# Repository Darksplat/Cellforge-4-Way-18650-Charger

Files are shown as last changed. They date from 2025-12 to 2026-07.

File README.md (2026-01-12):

# CellForge – 4 Way 18650 Charger & Analytics Platform

CellForge is an open hardware and software project for testing, analysing, and cataloguing 18650 lithium-ion cells.

It is inspired by Brett Watt’s original ASCD Nano charger and extends the concept with modern hardware, Wi-Fi connectivity, and a web-based analytics platform.

This repository contains **firmware, hardware, documentation, and web platform components** required to build and operate a connected 4-bay charger.

---

## Project Components

### Hardware
- 4-slot 18650 charger / discharger
- TP5100 charge controllers per slot
- Dual ADS1115 (16-bit I²C ADCs)
  - Battery voltage sensing
  - Load / discharge voltage sensing
- DS18B20 temperature sensors
- Active cooling with PWM fan control
- 3.3 V logic throughout (ESP32-safe)

### Firmware
- Target: **Arduino Nano ESP32 (ESP32-S3)**
- Wi-Fi connectivity
- Server heartbeat (PING) protocol
- RSSI (signal strength) reporting
- Internal resistance measurement
- Capacity and energy calculation
- Modular PlatformIO-based build

### Web Platform
- PHP + MySQL backend
- User authentication
- Charger registration and claiming
- Live charger connectivity status
- Signal strength visualisation
- Cell inventory
- Run ingestion (start, IR, complete, error)
- Cron-based offline detection

### Data
- Cell metadata (barcode-centric)
- Internal resistance results
- Capacity (mAh) and energy (Wh)
- Charger telemetry (presence, RSSI)

---

## Current Status

- Firmware: **Stable, Wi-Fi enabled**
- Connectivity: **Server-authoritative heartbeat**
- Telemetry: **RSSI reporting live**
- Offline detection: **Cron-enforced**
- UI: **Live status, signal bars, local time rendering**

---

## Repository Structure (high-level)

---

## Design Principles

- Server decides truth (presence, offline state)
- Firmware reports facts, not assumptions
- Browser renders user-local time
- Hardware remains Brett-compatible where practical
- Electrical safety first (3.3 V logic, no mixed-voltage traps)

---

## Licensing

Original ASCD Nano work:
- © Brett Watt
- Creative Commons BY-NC-SA 3.0

CellForge modifications:
- © Jeremy Younger
- Released under the same license unless otherwise stated

---

## Disclaimer

This project involves lithium-ion cells.
Improper use can result in fire, injury, or property damage.

You are responsible for ensuring safe construction, operation, and supervision.

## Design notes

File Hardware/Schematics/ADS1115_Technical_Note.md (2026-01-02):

ADS1115 Technical Note
Rationale, Configuration, and Integration in V2
This note explains why the ADS1115 was selected, how it is configured in the V2 schematic, and how it replaces the analogue multiplexer used in Brett’s original Arduino Nano design.
1. Why ADS1115 was chosen
The ADS1115 was selected to address the key limitations of the original analogue sensing approach:
Limitations in V1 (mux + MCU ADC)
10-bit ADC resolution (ATmega328P)
Shared SIG line susceptible to:
switching transients
settling-time errors
Sequential sampling via S0–S3
Firmware complexity around mux timing
Advantages of ADS1115
16-bit resolution (up to 32768 counts)
True differential-capable architecture (used single-ended here)
Per-channel input sampling without analogue switching
Stable, repeatable readings
Operates natively at 3.3 V
Widely supported, proven, inexpensive
The ADS1115 provides cleaner data with simpler firmware, without changing the charger’s electrical behaviour.
2. ADS1115 role in the V2 design
Two ADS1115 devices are used:
Device	I²C Address	Purpose
ADS1115 #1	0x48 (ADDR = GND)	Battery voltages BV1–BV4
ADS1115 #2	0x49 (ADDR = 3V3)	Load voltages RV1–RV4
Each ADS1115 uses:
Single-ended inputs
One channel per measurement
Shared I²C bus (SDA/SCL)
This mirrors the logical separation Brett already used (battery vs load sensing), just without the mux.
3. Electrical configuration (schematic-level)
Power
VDD = 3.3 V
GND = system ground
Local 100 nF decoupling capacitor per ADS1115
I²C
SDA / SCL pulled up to 3.3 V
No level shifting required
ALERT/RDY pin unused (left unconnected)
Address selection
ADDR tied to GND → address 0x48
ADDR tied to 3V3 → address 0x49
This avoids bus contention and allows both devices to coexist cleanly.
4. Firmware implications (high level)
What is removed
No S0–S3 control
No SIG analogue reads
No mux settling delays
What replaces it
Each voltage is read directly:
ads.readADC_SingleEnded(channel);
Where channel is 0–3 corresponding to BVx or RVx.
Scaling
The existing resistor divider ratios remain unchanged
Only the ADC conversion changes
Brett’s original scaling math is reused
This keeps calibration and interpretation consistent with the original design.
5. Performance and reliability benefits
Practical improvements
Less noise on voltage readings
No cross-channel coupling
Better low-current / near-end-of-charge resolution
More consistent logging results
System-level benefits
Simplified schematic
Fewer failure points
Easier debugging
Cleaner PCB routing
6. What ADS1115 does not change
To be explicit, ADS1115 does not:
Alter TP5100 charge behaviour
Change DFET/CFET control logic
Affect timing of charge/discharge cycles
Replace any safety or control logic
It is a measurement upgrade only.
7. Summary
The ADS1115 replaces the analogue multiplexer and MCU ADC with a dedicated, high-resolution measurement subsystem that:
Preserves Brett’s original design intent
Improves accuracy and reliability
Simplifies both schematic and firmware
Aligns naturally with a 3.3 V ESP32 platform
It is a modernisation, not a redesign.

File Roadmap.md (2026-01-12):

# CellForge Roadmap

This roadmap describes the intended development direction of the CellForge project.
It is not a promise of timelines; items may move or change as the project evolves.

The focus is on reliability, safety, and real-world usability.

---

## Firmware

### Completed
- ESP32 Nano (ESP32-S3) platform migration
- Wi-Fi connectivity
- Server heartbeat (PING) protocol
- Connection state reporting (CONNECTED / CONNECTING)
- RSSI (Wi-Fi signal strength) reporting
- ADS1115 external ADC integration
- PWM fan control using ESP32 `ledc`
- Multi-sensor temperature support
- Legacy compatibility for original state machine logic

### Planned
- Firmware build/version reporting to server
- Charger-side error codes surfaced in UI
- Optional heartbeat interval configuration
- OTA update strategy (future, not immediate)

---

## Hardware

### Completed
- ESP32-safe 3.3 V logic domain
- Dual ADS1115 voltage measurement architecture
- Removal of analogue multiplexer
- TP5100 charge status GPIO integration
- Shift-register-based MOSFET control
- Electrical rule check (ERC) validation

### Planned
- PCB V2 layout validation
- Thermal optimisation review
- Enclosure finalisation
- Connector and strain relief improvements

---

## Website / Backend

### Completed
- User authentication (register / login / logout)
- Charger registration via API token
- Charger claiming workflow
- Live connection status indicators
- RSSI signal strength visualisation
- Local-time rendering for timestamps
- Cron-based offline detection
- Runs ingest pipeline (start, IR, complete, error)
- Cell inventory management

### Planned
- Per-charger detail pages
- Charger telemetry history (RSSI, uptime)
- Run history visualisation (charts)
- Per-cell performance trends
- Alerts (offline, weak signal, failed runs)
- Data export (CSV / JSON)

---

## Documentation

### Completed
- Changelog
- Project README
- Roadmap

### Planned
- Firmware flashing and recovery guide
- Hardware build and wiring guide
- API reference documentation
- Safety and operating guidelines

---

## Data & Integrations

### Completed
- Core schema for users, chargers, cells, and runs

### Planned
- Second Life Storage data scraping (cell metadata, images)
- Cell model normalisation
- Historical trend analysis

---

## Guiding Principles

- Server determines truth for connectivity and state
- Firmware reports measurements and facts only
- UI reflects backend state, not inference
- Safety and electrical correctness over speed
- Backward compatibility with Brett Watt’s design where practical

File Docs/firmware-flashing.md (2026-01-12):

# Firmware Flashing and Recovery Guide
## Arduino Nano ESP32 (ESP32-S3)

This document describes how to build, flash, and recover CellForge firmware on the Arduino Nano ESP32 (ESP32-S3).
It also documents common errors and their resolutions.

---

## Supported Hardware

- Arduino Nano ESP32 (ESP32-S3)
- USB-C connection (data-capable cable required)

---

## Build Environment

Recommended:
- PlatformIO (VS Code)

Supported:
- Arduino IDE (limited debugging support)

---

## Firmware Location

Firmware
- ASCD_Nano_PIO
  - ASCD_Nano_Cellforge
    - src
      - ASCD_Nano.ino
      - Pins.h
      - Secrets.h
      - WifiManager.h
      - StatusLED.h

---

## Configuration (Secrets.h)

Before flashing, ensure `Secrets.h` is configured.

Example:

```cpp
#pragma once

#define WIFI_SSID "your_wifi_ssid"
#define WIFI_PASSWORD "your_wifi_password"
#define CELLFORGE_API_TOKEN "your_api_token_here"

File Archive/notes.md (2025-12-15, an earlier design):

## Archived material
The contents of the `archive/` directory are provided for historical and
reference purposes only. Licensing and attribution remain with the original
authors and sources. This material is not relicensed under the MIT License
unless explicitly stated.

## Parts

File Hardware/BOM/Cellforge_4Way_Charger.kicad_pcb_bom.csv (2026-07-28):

Designator | Quantity | Value | Footprint | Package | MPN | DNP | Mount_Type | Description | MF | MAXIMUM_PACKAGE_HEIGHT | Price | Check_prices | STANDARD | PARTREV | SnapEDA_Link | MP | Description_1 | Availability | MANUFACTURER | Sim.Device | Sim.Pins
A1 | 1 | Arduino_Nano_ESP32 | Arduino_Nano |  |  |  | tht | Arduino Nano board based on the ESP32-S3 with a dual-core 240 MHz processor, 384 kB ROM, 512 kB SRAM. Operates at 3.3V, with 5V USB-C® input and 6-21V VIN. Features Wi-Fi®, Bluetooth® LE, digital and analog pins, and supports SPI, I2C, UART, I2S, and CAN.
BT1 | 1 | BK-18650-PC8 | BAT_BK-18650-PC8 | None |  |  | tht |  | MPD | 21.54 mm | None | https://www.snapeda.com/parts/BK-18650-PC8/MPD/view-part/?ref=eda | Manufacturer Recommendations | L | https://www.snapeda.com/parts/BK-18650-PC8/MPD/view-part/?ref=snap | BK-18650-PC8 | Battery Holder (Open) 18650 4 Cell PC Pin | In Stock | MPD
BZ1 | 1 | Buzzer | Buzzer_15x7.5RM7.6 |  |  |  | tht | Buzzer, polarized
C1, C11, C2 | 3 | 100uF | CP_Radial_D5.0mm_P2.00mm |  |  |  | tht | Polarized capacitor
C10, C13, C3, C4, C5, C6, C7, C8, C9 | 9 | 100nF | C_0603_1608Metric_Pad1.08x0.95mm_HandSolder |  |  |  | smt | Unpolarized capacitor
C12, C16, C17, C18 | 4 | C | C_Disc_D5.0mm_W2.5mm_P2.50mm |  |  |  | tht | Unpolarized capacitor
C14 | 1 | 10nF | C_0603_1608Metric_Pad1.08x0.95mm_HandSolder |  |  |  | smt | Unpolarized capacitor
D1 | 1 | 1N4007 | D_DO-41_SOD81_P10.16mm_Horizontal |  |  |  | tht | 1000V 1A General Purpose Rectifier Diode, DO-41 |  |  |  |  |  |  |  |  |  |  |  | D | 1=K 2=A
J1 | 1 | Jack-DC | BarrelJack_CUI_PJ-063AH_Horizontal_CircularHoles |  |  |  | tht | DC Barrel Jack
J2 | 1 | Conn_01x02_MountingPin | JST_XH_B2B-XH-A_1x02_P2.50mm_Vertical |  |  |  | tht | Generic connectable mounting pin connector, single row, 01x02, script generated (kicad-library-utils/schlib/autogen/connector/)
J3, J4, J6, J7 | 4 | Screw_Terminal_01x02 | TerminalBlock_Phoenix_PT-1,5-2-5.0-H_1x02_P5.00mm_Horizontal |  |  |  | tht | Generic screw terminal, single row, 01x02, script generated (kicad-library-utils/schlib/autogen/connector/)
J5 | 1 | Conn_01x04_Socket | PinSocket_1x04_P2.54mm_Vertical |  |  |  | tht | Generic connector, single row, 01x04, script generated
J8 | 1 | Conn_01x02_Pin | PADS |  |  |  | smt | Generic connector, single row, 01x02, script generated
Q1 | 1 | BD139 | TO-126-3_Vertical |  |  |  | tht | 1.5A Ic, 80V Vce, Low Voltage Transistor, TO-126
Q10, Q6, Q7, Q9 | 4 | BC547 | TO-92_Inline |  |  |  | tht | 0.1A Ic, 45V Vce, Small Signal NPN Transistor, TO-92
Q11, Q12, Q13, Q14, Q15, Q16, Q17, Q19 | 8 | IRLZ44N | TO-220-3_Vertical |  |  |  | tht | 47A Id, 55V Vds, 22mOhm Rds Single N-Channel HEXFET Power MOSFET, TO-220AB
Q18, Q20, Q21, Q22 | 4 | FQP27P06 | TO-220-3_Vertical |  |  |  | tht | -27A Id, -60V Vds, QFET P-Channel MOSFET, TO-220
Q2, Q23, Q3, Q8 | 4 | AO3401A | SOT-23 |  |  |  | smt | -4.0A Id, -30V Vds, P-Channel MOSFET, SOT-23
R1, R21, R32, R36 | 4 | 4.7K | R_1206_3216Metric_Pad1.30x1.75mm_HandSolder |  |  |  | smt | Resistor
R10, R11, R12, R13, R14, R15, R16, R17, R18, R19, R4, R5, R6, R7, R8, R9 | 16 | 100K | R_1206_3216Metric_Pad1.30x1.75mm_HandSolder |  |  |  | smt | Resistor
R2, R20, R3, R35, R43, R50 | 6 | 10K | R_1206_3216Metric_Pad1.30x1.75mm_HandSolder |  |  |  | smt | Resistor
R22 | 1 | 1K | R_1206_3216Metric_Pad1.30x1.75mm_HandSolder |  |  |  | smt | Resistor
R23 | 1 | 1k | R_1206_3216Metric_Pad1.30x1.75mm_HandSolder |  |  |  | smt | Resistor
R33, R34, R37, R38, R39, R40, R41, R42, R44 | 9 | 470R | R_1206_3216Metric_Pad1.30x1.75mm_HandSolder |  |  |  | smt | Resistor
SW1 | 1 | SW_Push | SW_PUSH_6mm |  |  |  | tht | Push button switch, generic, two pins
TP5100_Module1, TP5100_Module2, TP5100_Module3, TP5100_Module4 | 4 | ~ | Untitled |  |  |  | tht
U1, U2, U3, U4, U7 | 5 | DS18B20 | TO-92_Inline |  |  |  | tht | Programmable Resolution 1-Wire Digital Thermometer TO-92
U5 | 1 | 74HC595 | DIP-16_W7.62mm |  |  |  | tht | 8-bit serial in/out Shift Register 3-State Outputs
U6, U9 | 2 | ZC261500 | MODULE_ZC261500 | None |  |  | tht |  | YKS | NA | None | https://www.snapeda.com/parts/ZC261500/YKS/view-part/?ref=eda | Manufacturer Recommendations | NA | https://www.snapeda.com/parts/ZC261500/YKS/view-part/?ref=snap | ZC261500 | ADS1115 Module ADC 4 channel with Pro Gain Amplifier for Arduino RPi | Not in stock | YKS

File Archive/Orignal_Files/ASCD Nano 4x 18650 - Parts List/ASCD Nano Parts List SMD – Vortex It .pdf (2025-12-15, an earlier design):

### The Wayback Machine - https://web.archive.org/web/20220126044014/https://www.vortexi…

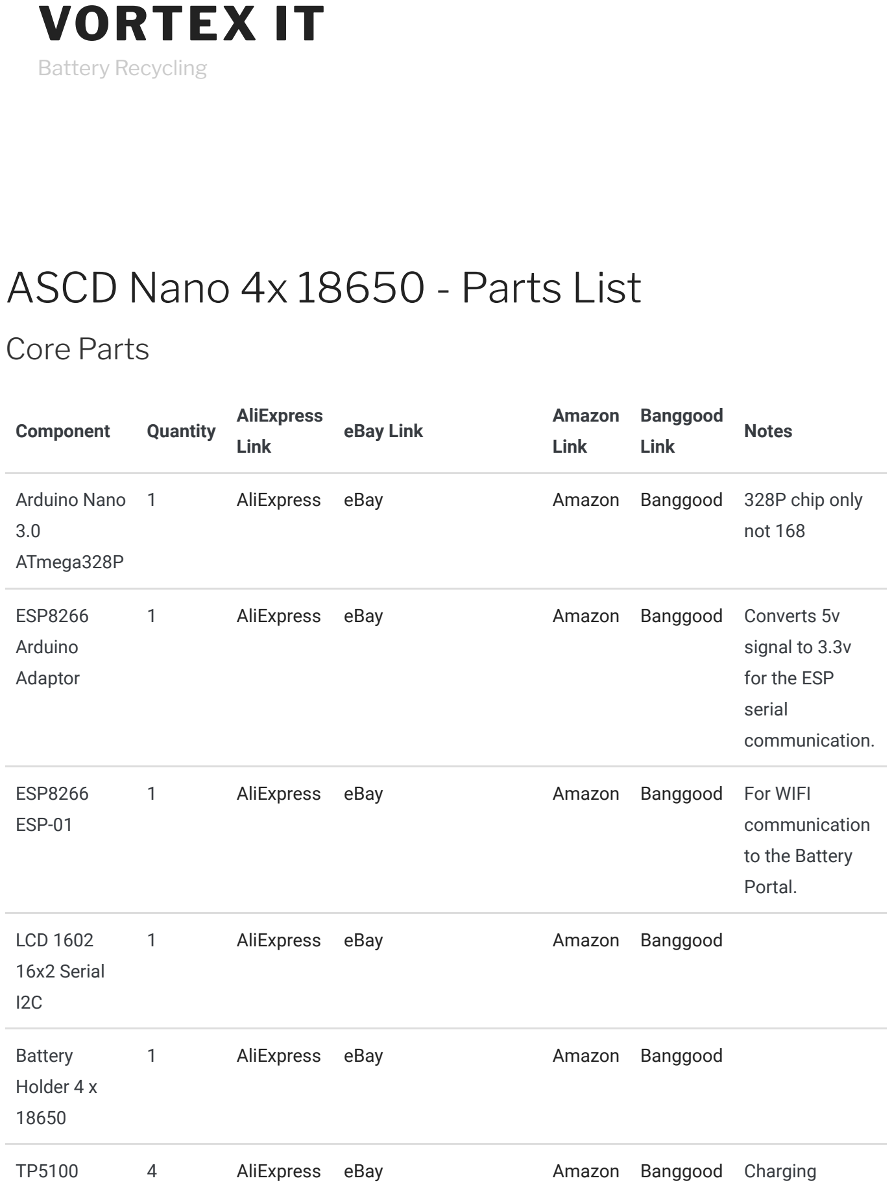
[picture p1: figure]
ASCD Nano 4x 18650 - Parts List; Core Parts; Component; Quantity; AliExpress; Link; eBay Link; Amazon Link; Banggood Link; Notes; Arduino Nano 3.0 ATmega328P; AliExpress eBay; Amazon Banggood 328P chip only; not 168; ESP8266 Arduino Adaptor; Amazon Banggood Converts 5v; signal to 3.3v for the ESP serial communication.; ESP8266 ESP-01; Amazon Banggood For WIFI; communication to the Battery Portal.; LCD 1602 16x2 Serial I2C; Amazon Banggood; Battery Holder 4 x 18650; Amazon Banggood Charging; VORTEX IT; Battery Recycling

Module | | modules. Check PCB footprint.

CD74HC4067
Module
1 | AliExpress (https://web.archive.org/web/20220126044014/http://bit.ly/2G0dxFU) eBay (https://web.archive.org/web/20220126044014/https://ebay.us/WXJNwM) | Amazon (https://web.archive.org/web/20220126044014/https://amzn.to/2ZuhIP1) Banggood (https://web.archive.org/web/20220126044014/https://www.banggood.com/custlink/DK33amgB9K) Be careful on PCB size some are larger

74HC595N
DIP16
1 | AliExpress (https://web.archive.org/web/20220126044014/http://bit.ly/2RIV9Tc) eBay (https://web.archive.org/web/20220126044014/https://ebay.us/LD0g7W) | Amazon (https://web.archive.org/web/20220126044014/https://amzn.to/2Hq9hhk) Banggood (https://web.archive.org/web/20220126044014/https://www.banggood.com/custlink/KGKKOm4b8d) Shift out Register
DIP16 Socket 1 | AliExpress (https://web.archive.org/web/20220126044014/http://bit.ly/2FePNOb) eBay (https://web.archive.org/web/20220126044014/https://ebay.us/mmJGwL) | Amazon (https://web.archive.org/web/20220126044014/https://amzn.to/2KYAE4k) Banggood (https://web.archive.org/web/20220126044014/https://www.banggood.com/custlink/Km3vlG4QZ6)

Temp Sensor
DS18B20
5 | AliExpress (https://web.archive.org/web/20220126044014/http://bit.ly/2T17VOt) eBay (https://web.archive.org/web/20220126044014/https://ebay.us/SWY1sO) | Amazon (https://web.archive.org/web/20220126044014/https://amzn.to/2NvYIgu) Banggood (https://web.archive.org/web/20220126044014/https://www.banggood.com/custlink/G3vGo3eAIU) Tes before soldering.

Tactile
Switch 6MM
1 | AliExpress (https://web.archive.org/web/20220126044014/http://bit.ly/2qFAR1j) eBay (https://web.archive.org/web/20220126044014/https://ebay.us/pZmwQm) | Amazon (https://web.archive.org/web/20220126044014/https://amzn.to/2KW5OcE) Banggood (https://web.archive.org/web/20220126044014/https://www.banggood.com/custlink/vD3ma3gslv)

Connector
KF301-2P
5.08mm
4 | AliExpress (https://web.archive.org/web/20220126044014/http://bit.ly/2PQP1uB) eBay (https://web.archive.org/web/20220126044014/https://ebay.us/JwZTQG) | Amazon (https://web.archive.org/web/20220126044014/https://amzn.to/2ZgH6fP) Banggood (https://web.archive.org/web/20220126044014/https://www.banggood.com/custlink/3DDvjGeNaE) Optional - For connecting the Discharge resistors or JST

DC Jack 5.5 x
2.1mm
1 | AliExpress (https://web.archive.org/web/20220126044014/http://bit.ly/2DsUyC7) eBay (https://web.archive.org/web/20220126044014/https://ebay.us/suEAMA) | Amazon (https://web.archive.org/web/20220126044014/https://amzn.to/2Nzxiqj) Banggood (https://web.archive.org/web/20220126044014/https://www.banggood.com/custlink/GmK3j34An5) 12V power input

Resistor
Carbon Film
3.3ohm 5W
4 | AliExpress (https://web.archive.org/web/20220126044014/http://bit.ly/2Niuaer) eBay (https://web.archive.org/web/20220126044014/https://ebay.us/b2B56O) | Amazon (https://web.archive.org/web/20220126044014/https://amzn.to/2ZrIs6K) Banggood (https://web.archive.org/web/20220126044014/https://www.banggood.com/custlink/mmGKl30kyn) Banggood is 3Ohm Aluminum. 6.8Ohm for 500mA discharge.

Conical
Rubber Feet
14x8mm
8 | AliExpress (https://web.archive.org/web/20220126044014/http://bit.ly/2zGEQ1G) eBay (https://web.archive.org/web/20220126044014/https://ebay.to/2SYO5TG) | Amazon (https://web.archive.org/web/20220126044014/https://amzn.to/323tYHR) Banggood (https://web.archive.org/web/20220126044014/https://www.banggood.com/custlink/vv3GlDgzrW) For non 3D print case design screwed to 35mm standoffs

Insulating
Washers
3x7x0.8mm
16 | AliExpress (https://web.archive.org/web/20220126044014/http://bit.ly/2Dy5A8X) eBay (https://web.archive.org/web/20220126044014/https://ebay.us/9Nb9U8) | Amazon (https://web.archive.org/web/20220126044014/https://amzn.to/2Zqf8JB) Banggood (https://web.archive.org/web/20220126044014/https://www.banggood.com/custlink/mKKvLKe2Ca) Bangood link is nylon

M3 x 12mm
Flat Head
Stainless
Steel 304
Hex Socket
Screw
8 | AliExpress (https://web.archive.org/web/20220126044014/http://bit.ly/2uMlM0i) https://ebay.us/Z9pBrK Amazon (https://web.archive.org/web/20220126044014/https://amzn.to/327cpGU) Banggood (https://web.archive.org/web/20220126044014/https://www.banggood.com/custlink/3GGmj34qCQ) Optional - Used to mount the board and Battery Holder

M3 304
Stainless
Steel 304
Hex Nuts
4 | AliExpress (https://web.archive.org/web/20220126044014/http://bit.ly/2OdxLMr) eBay (https://web.archive.org/web/20220126044014/https://ebay.us/gZtNj0) | Amazon (https://web.archive.org/web/20220126044014/https://amzn.to/322Kzvm) Banggood (https://web.archive.org/web/20220126044014/https://www.banggood.com/custlink/KDmvLGBqPt) Optional - Used to mount the Battery Holder

M3 Standoff
18mm Brass
F-F
4 | AliExpress (https://web.archive.org/web/20220126044014/http://bit.ly/2PUnAA4) eBay (https://web.archive.org/web/20220126044014/https://ebay.to/2PUyDcO) | Amazon (https://web.archive.org/web/20220126044014/https://amzn.to/2HoBmWk) Banggood (https://web.archive.org/web/20220126044014/https://www.banggood.com/custlink/DvDmomeMFQ) For LCD mounting. Banggood link is for a pack

M3 Standoff
35mm brass
F-F
4 | AliExpress (https://web.archive.org/web/20220126044014/http://bit.ly/2PUnAA4) eBay (https://web.archive.org/web/20220126044014/https://ebay.to/2PUyDcO) | Amazon (https://web.archive.org/web/20220126044014/https://amzn.to/2L3GEra) Banggood (https://web.archive.org/web/20220126044014/https://www.banggood.com/custlink/DvDmomeMFQ) Optional - For non 3D print case standoffs. Banggood link is for a pack

Header
Female
2.54mm 1x4
1 | AliExpress (https://web.archive.org/web/20220126044014/http://bit.ly/2ZyXOCA) eBay (https://web.archive.org/web/20220126044014/https://ebay.to/2Hv9Tm2) | Amazon (https://web.archive.org/web/20220126044014/https://amzn.to/2ZtUOqP) Banggood (https://web.archive.org/web/20220126044014/https://www.banggood.com/custlink/3KmmoDBU8z) Bangood link is 40pin cut to size

Headers
Male
2.54mm
1x40 Pin
1 | AliExpress (https://web.archive.org/web/20220126044014/http://bit.ly/2KZBU7q) eBay (https://web.archive.org/web/20220126044014/https://ebay.to/2RRsITf) | Amazon (https://web.archive.org/web/20220126044014/https://amzn.to/2Hsvn2H) Banggood (https://web.archive.org/web/20220126044014/https://www.banggood.com/custlink/KvmDOv0zZo) Used for all headers

Header
Female Right
Angle
2.54mm 1x4
1 | AliExpress (https://web.archive.org/web/20220126044014/http://bit.ly/2qEVQ4f) eBay (https://web.archive.org/web/20220126044014/https://ebay.to/2qJ0kH3) | Amazon (https://web.archive.org/web/20220126044014/https://amzn.to/2KYF7nC) Banggood (https://web.archive.org/web/20220126044014/https://www.banggood.com/custlink/3KmmoKB2jv) For the ESP Adaptor. Banggood is a stackable 8P. Need to cut to size and bend.

USB to
ESP8266
ESP-01
1 | AliExpress (https://web.archive.org/web/20220126044014/http://bit.ly/2DABm5i) eBay (https://web.archive.org/web/20220126044014/https://ebay.to/2FkfrAY) | Amazon (https://web.archive.org/web/20220126044014/https://amzn.to/2ZrMUOL) Banggood (https://web.archive.org/web/20220126044014/https://www.banggood.com/custlink/3mGGo30zaJ) For programming the ESP you

Programmer | only need one.

Fan 80MM x
80MM x
15MM 12V
1 | AliExpress (https://web.archive.org/web/20220126044014/http://bit.ly/2Yezt4k) eBay (https://web.archive.org/web/20220126044014/https://ebay.us/20mG2e) | Amazon (https://web.archive.org/web/20220126044014/https://amzn.to/2NyxyWv) Banggood (https://web.archive.org/web/20220126044014/https://www.banggood.com/custlink/DDKvoDg2ot) For the new 3D
printed case
design.

BD139 NPN
Transistor
1 | AliExpress (https://web.archive.org/web/20220126044014/http://bit.ly/2CUlOGP) eBay (https://web.archive.org/web/20220126044014/https://ebay.to/2G0eQEe) | Amazon (https://web.archive.org/web/20220126044014/https://amzn.to/2ZrJkYT) | For the fan
speed controller

100uF 16V
Electrolytic
Capacitor
5x11mm
1 | AliExpress (https://web.archive.org/web/20220126044014/http://bit.ly/2sVOSsR) | eBay (https://web.archive.org/web/20220126044014/https://ebay.to/2Ga1nsJ) | Amazon (https://web.archive.org/web/20220126044014/https://amzn.to/2Zyk4QK) | Banggood (https://web.archive.org/web/20220126044014/https://www.banggood.com/custlink/mKDmam6MoU) | For the fan speed controller

JST 2.0 PH
2pin M-F
1 | AliExpress (https://web.archive.org/web/20220126044014/http://bit.ly/2ToX7sX) eBay (https://web.archive.org/web/20220126044014/https://ebay.to/2CXS9fO) | Amazon (https://web.archive.org/web/20220126044014/https://amzn.to/31Y1kIa) Banggood (https://web.archive.org/web/20220126044014/https://www.banggood.com/custlink/vKDvamgq6V) Optional - for the discharge resistors and fan output.

5V Active
Buzzer
1 | AliExpress (https://web.archive.org/web/20220126044014/http://bit.ly/2FIhDzb) eBay (https://web.archive.org/web/20220126044014/http://ebay.to/2CLoLKw) | Amazon (https://web.archive.org/web/20220126044014/https://amzn.to/3451xLF) Banggood (https://web.archive.org/web/20220126044014/https://www.banggood.com/custlink/KDvDoD4Msy) Optional

Header
Female
2.54mm 1x8
1 | AliExpress (https://web.archive.org/web/20220126044014/http://bit.ly/2ZyXOCA) eBay (https://web.archive.org/web/20220126044014/https://ebay.to/2Hv9Tm2) | Amazon (https://web.archive.org/web/20220126044014/https://amzn.to/2ZtUOqP) Banggood (https://web.archive.org/web/20220126044014/https://www.banggood.com/custlink/3KmmoDBU8z) Bangood link is 40pin cut to size

Header
Female
2.54mm
1x15
2 | AliExpress (https://web.archive.org/web/20220126044014/http://bit.ly/2ZyXOCA) eBay (https://web.archive.org/web/20220126044014/https://ebay.to/2Hv9Tm2) | Amazon (https://web.archive.org/web/20220126044014/https://amzn.to/2ZtUOqP) Banggood (https://web.archive.org/web/20220126044014/https://www.banggood.com/custlink/3KmmoDBU8z) Bangood link is 40pin cut to size

Header
Female
2.54mm
1x16
1 | AliExpress (https://web.archive.org/web/20220126044014/http://bit.ly/2ZyXOCA) eBay (https://web.archive.org/web/20220126044014/https://ebay.to/2Hv9Tm2) | Amazon (https://web.archive.org/web/20220126044014/https://amzn.to/2ZtUOqP) Banggood (https://web.archive.org/web/20220126044014/https://www.banggood.com/custlink/3KmmoDBU8z) Bangood link is 40pin cut to size

M3 x 4mm
Flat Head
Stainless
Steel 304
Hex Socket
Screw
8 | AliExpress (https://web.archive.org/web/20220126044014/http://bit.ly/2ZzQnig) eBay (https://web.archive.org/web/20220126044014/https://ebay.to/2JShOKc) | Amazon (https://web.archive.org/web/20220126044014/https://amzn.to/327cpGU) Banggood (https://web.archive.org/web/20220126044014/https://www.banggood.com/custlink/3GGmj34qCQ) For mounting the LCD

## SMD or THT Components

Component | Quantity | AliExpress
Link

eBay
Link

Amazon
Link

Banggood
Link

Notes

10k – 1/8w Resistor SMD
0603
7 | AliExpress (https://web.archive.org/web/20220126044014/http://bit.ly/2QCaKDJ) | eBay (https://web.archive.org/web/20220126044014/https://ebay.us/x6pmfp) | Amazon (https://web.archive.org/web/20220126044014/https://amzn.to/2U95Hxj) | Banggood (https://web.archive.org/web/20220126044014/https://www.banggood.com/custlink/D3KmoKAmYR)

4.7k – 1/8w Resistor SMD
0603
1 | AliExpress (https://web.archive.org/web/20220126044014/http://bit.ly/2QCaKDJ) | eBay (https://web.archive.org/web/20220126044014/https://ebay.us/fEahKI) | Amazon (https://web.archive.org/web/20220126044014/https://amzn.to/2zoWhEl) | Banggood (https://web.archive.org/web/20220126044014/https://www.banggood.com/custlink/D3KmoKAmYR)

1k – 1/8w Resistor SMD
0603
8 | AliExpress (https://web.archive.org/web/20220126044014/http://bit.ly/2QCaKDJ) | eBay (https://web.archive.org/web/20220126044014/https://ebay.us/oqAqhw) | Amazon (https://web.archive.org/web/20220126044014/https://amzn.to/2Lb0TDA) | Banggood (https://web.archive.org/web/20220126044014/https://www.banggood.com/custlink/D3KmoKAmYR)

N-Channel Mosfet
IRLML2502TRPBF
8 | AliExpress (https://web.archive.org/web/20220126044014/http://bit.ly/2PWwxZG) | eBay (https://web.archive.org/web/20220126044014/https://ebay.us/FgLAvg) | Amazon (https://web.archive.org/web/20220126044014/https://amzn.to/2L9nfoW)

P-Channel Mosfet AO3407
SOT-23
4 | AliExpress (https://web.archive.org/web/20220126044014/http://bit.ly/2UJTb6L) | eBay (https://web.archive.org/web/20220126044014/https://ebay.us/Dtovln) | Amazon (https://web.archive.org/web/20220126044014/https://amzn.to/2zpMEoT)

NPN Transistor SOT23
BC847
4 | AliExpress (https://web.archive.org/web/20220126044014/http://bit.ly/2B0a8Tk) | eBay (https://web.archive.org/web/20220126044014/https://ebay.us/2LquSn) | Amazon (https://web.archive.org/web/20220126044014/https://amzn.to/2KY7jXH)
Diode 1N4148 0603 | 2 | AliExpress (https://web.archive.org/web/20220126044014/http://bit.ly/2DyALB7) | eBay (https://web.archive.org/web/20220126044014/https://ebay.us/ehgVSZ) | Amazon (https://web.archive.org/web/20220126044014/https://amzn.to/2MHUym5)
THT Components (https://web.archive.org/web/20220126044014/https://www.vortexit.co.nz/parts-list-nano-4x/) | SMD Components (https://web.archive.org/web/20220126044014/https://www.vortexit.co.nz/parts-list-nano-4x/)

## Tools

Component | AliExpress Link | eBay
Link

Amazon
Link | Banggood Link | Notes
Solder Wire 60/40 0.7mm | AliExpress (https://web.archive.org/web/20220126044014/http://bit.ly/2IWmYDm) | eBay (https://web.archive.org/web/20220126044014/https://ebay.to/2w2QPVA)
Diagonal Pliers | AliExpress (https://web.archive.org/web/20220126044014/http://bit.ly/2kvDY8V) | eBay (https://web.archive.org/web/20220126044014/https://ebay.to/2w7ejZD)
A3 PVC Cutting Mat | AliExpress (https://web.archive.org/web/20220126044014/http://bit.ly/2IUh8T2) | eBay (https://web.archive.org/web/20220126044014/https://ebay.to/2MrRLgv)

Youyue 8586 SMD Soldering
Rework Station
AliExpress (https://web.archive.org/web/20220126044014/http://bit.ly/2IQGVQ9) | eBay (https://web.archive.org/web/20220126044014/https://ebay.to/2weX2xZ)
UNI-T UT39A Digital Multimeter | AliExpress (https://web.archive.org/web/20220126044014/http://bit.ly/2yKrAvI) | eBay (https://web.archive.org/web/20220126044014/https://ebay.to/2w9XVaG)
Wire Strippers | AliExpress (https://web.archive.org/web/20220126044014/http://bit.ly/2NzijZW) | eBay (https://web.archive.org/web/20220126044014/https://ebay.to/2JYDJz3)
Barcode Scanner | AliExpress (https://web.archive.org/web/20220126044014/http://bit.ly/2B2OOwu) | eBay (https://web.archive.org/web/20220126044014/https://ebay.to/2zMlgRU)
Barcode Printer | AliExpress (https://web.archive.org/web/20220126044014/http://bit.ly/2LB0r3K) | eBay (https://web.archive.org/web/20220126044014/https://ebay.to/2QI10bq)
Barcode Labels 30mm x 20mm x700 | AliExpress (https://web.archive.org/web/20220126044014/http://bit.ly/2AcgwII) | eBay (https://web.archive.org/web/20220126044014/https://ebay.to/2B3mLgj)
MECHANIC Solder Paste | AliExpress (https://web.archive.org/web/20220126044014/http://bit.ly/2wbZepY) | eBay (https://web.archive.org/web/20220126044014/https://ebay.to/2P7Tnu8)
Anti-Static Tweezers | AliExpress (https://web.archive.org/web/20220126044014/http://bit.ly/2MK8Xus) | eBay (https://web.archive.org/web/20220126044014/https://ebay.to/2Ox3eZs)
Third Hand Soldering Stand | AliExpress (https://web.archive.org/web/20220126044014/http://bit.ly/2w8Fymz) | eBay (https://web.archive.org/web/20220126044014/https://ebay.to/2Bciklx)
AMTECH NC-559-ASM No-Clean Solder Flux | AliExpress (https://web.archive.org/web/20220126044014/http://bit.ly/2Mr7DQl) | eBay (https://web.archive.org/web/20220126044014/https://ebay.to/2nIuQzy)
Solder Wick | AliExpress (https://web.archive.org/web/20220126044014/http://bit.ly/2MPOCEd) | eBay (https://web.archive.org/web/20220126044014/https://ebay.to/2MPZvWt)
Precision Magnetic Screwdriver Set | AliExpress (https://web.archive.org/web/20220126044014/http://bit.ly/2MygOhV) | eBay (https://web.archive.org/web/20220126044014/https://ebay.to/2waflUJ)

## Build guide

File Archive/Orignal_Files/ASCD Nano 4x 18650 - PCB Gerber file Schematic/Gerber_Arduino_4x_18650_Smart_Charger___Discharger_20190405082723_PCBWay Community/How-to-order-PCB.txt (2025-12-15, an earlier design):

How to Order PCB

Please refer to:
https://docs.easyeda.com/en/PCB/Order-PCB

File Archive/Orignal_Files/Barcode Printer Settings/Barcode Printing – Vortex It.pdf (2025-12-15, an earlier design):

The Wayback Machine - https://web.archive.org/web/20220126051749/https://www.vortexi…

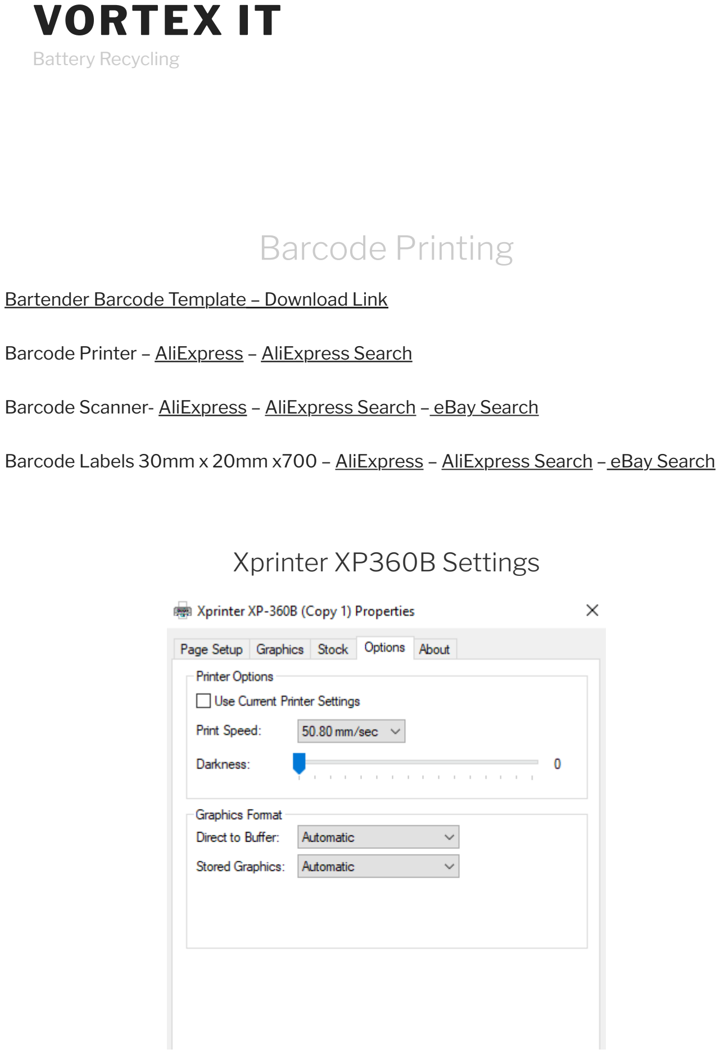
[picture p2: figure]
Barcode Printing; Xprinter XP360B Settings; VORTEX IT; Battery Recycling

Bartender Barcode Template (https://web.archive.org/web/20220126051749/http://vortexit.co.nz/bartender_barcode_template.zip) – Download Link

Barcode Printer – AliExpress (https://web.archive.org/web/20220126051749/http://bit.ly/2LB0r3K) – AliExpress Search (https://web.archive.org/web/20220126051749/https://bit.ly/3hvAsKz)

Barcode Scanner- AliExpress (https://web.archive.org/web/20220126051749/https://bit.ly/3bvoE7m) – AliExpress Search (https://web.archive.org/web/20220126051749/https://bit.ly/3yi1ZVG) – eBay Search (https://web.archive.org/web/20220126051749/https://ebay.us/b18FYo)

Barcode Labels 30mm x 20mm x700 – AliExpress (https://web.archive.org/web/20220126051749/http://bit.ly/2AcgwII) – AliExpress Search (https://web.archive.org/web/20220126051749/https://bit.ly/3olyNbS) – eBay Search (https://web.archive.org/web/20220126051749/https://ebay.us/b18FYo)

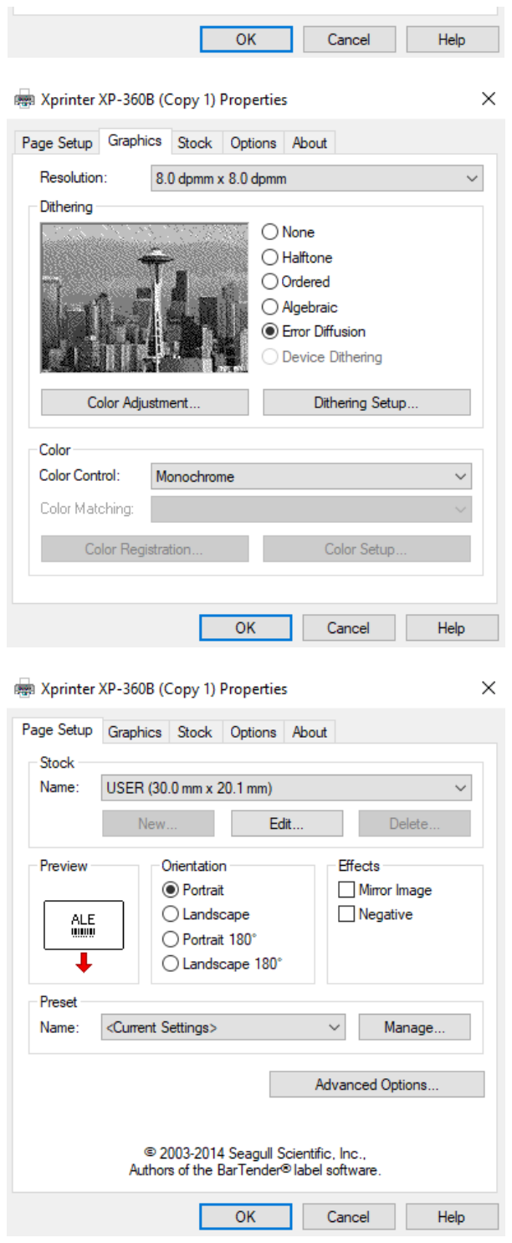
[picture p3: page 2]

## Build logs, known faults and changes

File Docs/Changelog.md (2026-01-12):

# Changelog

All notable changes to this project are documented in this file.

The format broadly follows *Keep a Changelog*.
This project uses pragmatic semantic versioning where appropriate.

---

## [0.4.0] – Live connectivity, telemetry & web platform integration

### Added
- Server-authoritative charger heartbeat (`PING`) protocol
- ESP32 firmware Wi-Fi heartbeat with state reporting
- RSSI (Wi-Fi signal strength) telemetry from firmware
- RSSI storage (`wifi_rssi`) in chargers table
- Traffic-light connection status (CONNECTED / CONNECTING / DISCONNECTED)
- Automatic charger offline detection via cron job
- Charger claiming workflow (unclaimed → user-owned)
- Browser-local time rendering for charger last-seen timestamps
- Signal strength visualisation (bars) in Chargers UI

### Changed
- Connection status is now backend-driven (no browser inference)
- Charger presence determined by server + cron, not firmware assumptions
- Time display moved from server formatting to browser-local rendering

### Fixed
- Timezone offset errors caused by mixed UTC / local comparisons
- Chargers remaining falsely “connected” after power loss
- Missing heartbeat handling in API ingest endpoint

### Status
- End-to-end connectivity verified with real ESP32 hardware
- Heartbeat, RSSI, cron enforcement, and UI fully coherent

---

## [0.3.0] – ESP32 Nano hardware refactor & ADC architecture finalised

### Added
- Finalised migration to **Arduino Nano ESP32 (ESP32-S3)** as drop-in controller
- Dual **ADS1115 (16-bit I²C ADC)** architecture replacing analogue multiplexer:
  - ADS1115 @ `0x48` for battery voltages (BV1–BV4)
  - ADS1115 @ `0x49` for load voltages (RV1–RV4)
- All ADS1115 devices powered from 3.3 V with local 100 nF decoupling
- I²C bus standardised to 3.3 V pull-ups (ESP32-safe)
- TP5100 charge-status lines (CD1–CD4) converted to direct GPIO inputs with
  per-module 10 kΩ pull-ups to 3.3 V
- 74HC595 shift register retained for DFET / CFET control, now:
  - Powered from 3.3 V
  - OE tied to GND
  - MR tied to 3.3 V
- Power strategy finalised:
  - VIN (6–21 V) fed directly from 12 V barrel jack
  - USB-C used for programming and testing
  - Logic rail entirely 3.3 V
- ERC completed with only expected warnings (no electrical errors)

### Changed
- Removed analogue multiplexer (CD74HC4067) and all associated select logic
- Replaced all analogue reads with ADS1115 channel reads while preserving
  original state-machine flow
- Pin mapping deliberately aligned to Brett Watt’s original Arduino Nano V3
  schematic to minimise firmware and PCB changes
- Shift-register control pins (DS, SH/CP, ST/CP) kept identical at net level
- Temperature bus (DS18B20) retained on original pin, explicitly pulled up to 3.3 V
- Fan control retained on original pin and validated for 3.3 V drive
- All logic-side pull-ups migrated from 5 V → 3.3 V
- +5 V rail removed from logic domain (retained only where isolated probes require)

### Fixed
- Eliminated mixed-voltage logic issues inherited from ATmega328P design
- Removed all dependencies on 5 V logic thresholds
- Resolved ERC issues related to:
  - Floating ADC address pins
  - Power-flag ambiguity on VIN
- Prevented ESP32 GPIO over-voltage risks on TMP, I²C, and CD lines

### Status
- Schematic electrically complete and ESP32-safe
- Pin mapping locked and Brett-compatible
- Ready for firmware ADS1115 integration, bench validation, and PCB layout

---

## [0.2.0] – ESP32 Nano port & PlatformIO stabilisation

### Added
- Initial migration from Arduino Nano (ATmega328P) to Arduino Nano ESP32 (ESP32-S3)
- PlatformIO environment configured for `arduino_nano_esp32`
- Modular firmware structure validated (`.ino` / `.h` separation)
- Initial ADS1115 support introduced (external ADC)
- ESP32-native PWM fan control using `ledc`
- Debug configuration system (`DebugConfig.h`) with compile-time enable/disable
- Temperature sensor enumeration updated for 6× DS18B20 sensors
- Legacy compatibility wrapper for original `readMux()` logic

### Changed
- Removed AVR-specific assumptions and ESP8266 remnants
- Refactored pin definitions into `Pins.h`
- Began transition from mux-based ADC reads to ADS1115

### Fixed
- Compile-blocking syntax and macro conflicts
- Header include ordering for ESP32 toolchain
- Missing Python dependency (`intelhex`) in ESP32 build chain

---

## [0.1.0] – Repository restructure & archive recovery

### Added
- Initial repository creation
- Legacy Arduino Nano firmware archived
- Hardware files, documentation, and historical reference material organised

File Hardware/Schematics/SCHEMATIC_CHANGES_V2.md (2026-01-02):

Arduino 4× 18650 Smart Charger
V2 Schematic Change Summary (Brett-Compatible)
This document summarises the intentional schematic changes made in V2 relative to Brett Watt’s original Arduino Nano V3 (ATmega328P) design.
The goal of V2 is to modernise the controller and measurement architecture without changing the core charge/discharge behaviour or control topology.
1. Microcontroller platform change
Original (V1)
Arduino Nano V3 (ATmega328P)
5 V logic domain
Limited ADC resolution and channel count
V2
Arduino Nano ESP32 (ESP32-S3)
3.3 V logic domain
VIN range retained (6–21 V) for direct 12 V barrel-jack supply
USB-C used for programming and development
Rationale
Modern MCU with Wi-Fi/BLE capability
Significantly higher processing headroom
Native USB-C
Long-term availability
The ESP32 Nano is treated as a drop-in controller, not a functional redesign.
2. Analogue measurement architecture (major change)
Original (V1)
CD74HC4067 analogue multiplexer
Shared SIG line into ATmega ADC
Select lines S0–S3
Sequential sampling of:
Battery voltages (BVx)
Load voltages (RVx)
TP5100 status via mux
V2
Analogue multiplexer completely removed
Replaced with two ADS1115 16-bit I²C ADCs
ADS1115	Address	Function
U14	0x48 (ADDR = GND)	Battery voltages BV1–BV4
U15	0x49 (ADDR = 3V3)	Load voltages RV1–RV4
All ADC inputs are single-ended
I²C bus pulled up to 3.3 V
Local 100 nF decoupling per ADC
Rationale
Removes mux timing complexity
Higher resolution and repeatability
Parallel access to all channels
Cleaner firmware model (no SIG or select logic)
Firmware preserves Brett’s state machine but replaces analogRead(SIG) with ADS1115 channel reads.
3. TP5100 charge status sensing
Original (V1)
CD1–CD4 routed through the analogue mux
Read indirectly via SIG
V2
CD1–CD4 are direct GPIO inputs
Each CD line:
Has its own 10 kΩ pull-up to 3.3 V
Connects directly to the ESP32
Charger	ESP32 pin (Brett-aligned)
CD1	D12
CD2	D11
CD3	D10
CD4	D9
Rationale
TP5100 outputs are digital status signals
ADC/mux path was unnecessary
Improves reliability and simplifies logic
4. Shift register control (unchanged in concept)
Original (V1)
74HC595 powered from 5 V
Driven by ATmega GPIO
Controls DFET/CFET lines
V2
74HC595 retained
Now powered from 3.3 V
Control signals unchanged at the net level:
DS
SH/CP
ST/CP
OE tied to GND
MR tied to 3.3 V
Rationale
Maintains identical charge/discharge control behaviour
3.3 V logic is fully sufficient for downstream transistor stages
Eliminates mixed-voltage logic risks
5. Pin mapping philosophy
A key design goal in V2 was to keep pin names and usage identical to Brett’s schematic wherever possible.
Kept identical
DS, SH/CP, ST/CP
TMP (DS18B20 bus) on D4
FAN on D5
BTN, BUZZ
I²C on A4/A5
VIN on VIN
Reused pins
Former mux select pins (S0–S3) are now used for CD1–CD4
No new GPIOs introduced unless strictly required
Result
Firmware diffs are small and readable
PCB routing changes are minimal
Original mental model remains valid
6. Temperature sensing
Original (V1)
DS18B20 sensors
5 V pull-up on OneWire bus
V2
DS18B20 sensors retained
Pull-up moved to 3.3 V
ESP32-safe logic levels
7. Fan control
Fan driver topology unchanged
Control pin unchanged
Verified to operate correctly from 3.3 V drive
8. Power domain changes
Logic power
Entire logic domain is now 3.3 V
No 5 V logic remains
VIN
12 V barrel jack feeds VIN directly
ESP32 onboard regulator generates 3.3 V
USB-C may be connected simultaneously for programming
Important
VBUS (USB 5 V) is not used as a system rail
9. Removed elements
The following are intentionally removed in V2:
CD74HC4067 analogue multiplexer
SIG analogue bus
S0–S3 select logic
5 V pull-ups on logic signals
Any 74HCT logic
10. What has NOT changed
TP5100 charge/discharge topology
Load resistor arrangement
DFET/CFET transistor stages
Overall charger behaviour and sequencing logic
Mechanical layout concept (4 independent bays)
Summary
V2 is a modernised controller and sensing architecture built on top of Brett’s proven charger design.
Control logic philosophy is unchanged
Measurement is cleaner, higher resolution, and simpler
Logic voltage is unified at 3.3 V
ESP32 provides a future-proof platform
If you understand Brett’s original schematic, V2 should feel immediately familiar — just without the mux and with much better ADCs.

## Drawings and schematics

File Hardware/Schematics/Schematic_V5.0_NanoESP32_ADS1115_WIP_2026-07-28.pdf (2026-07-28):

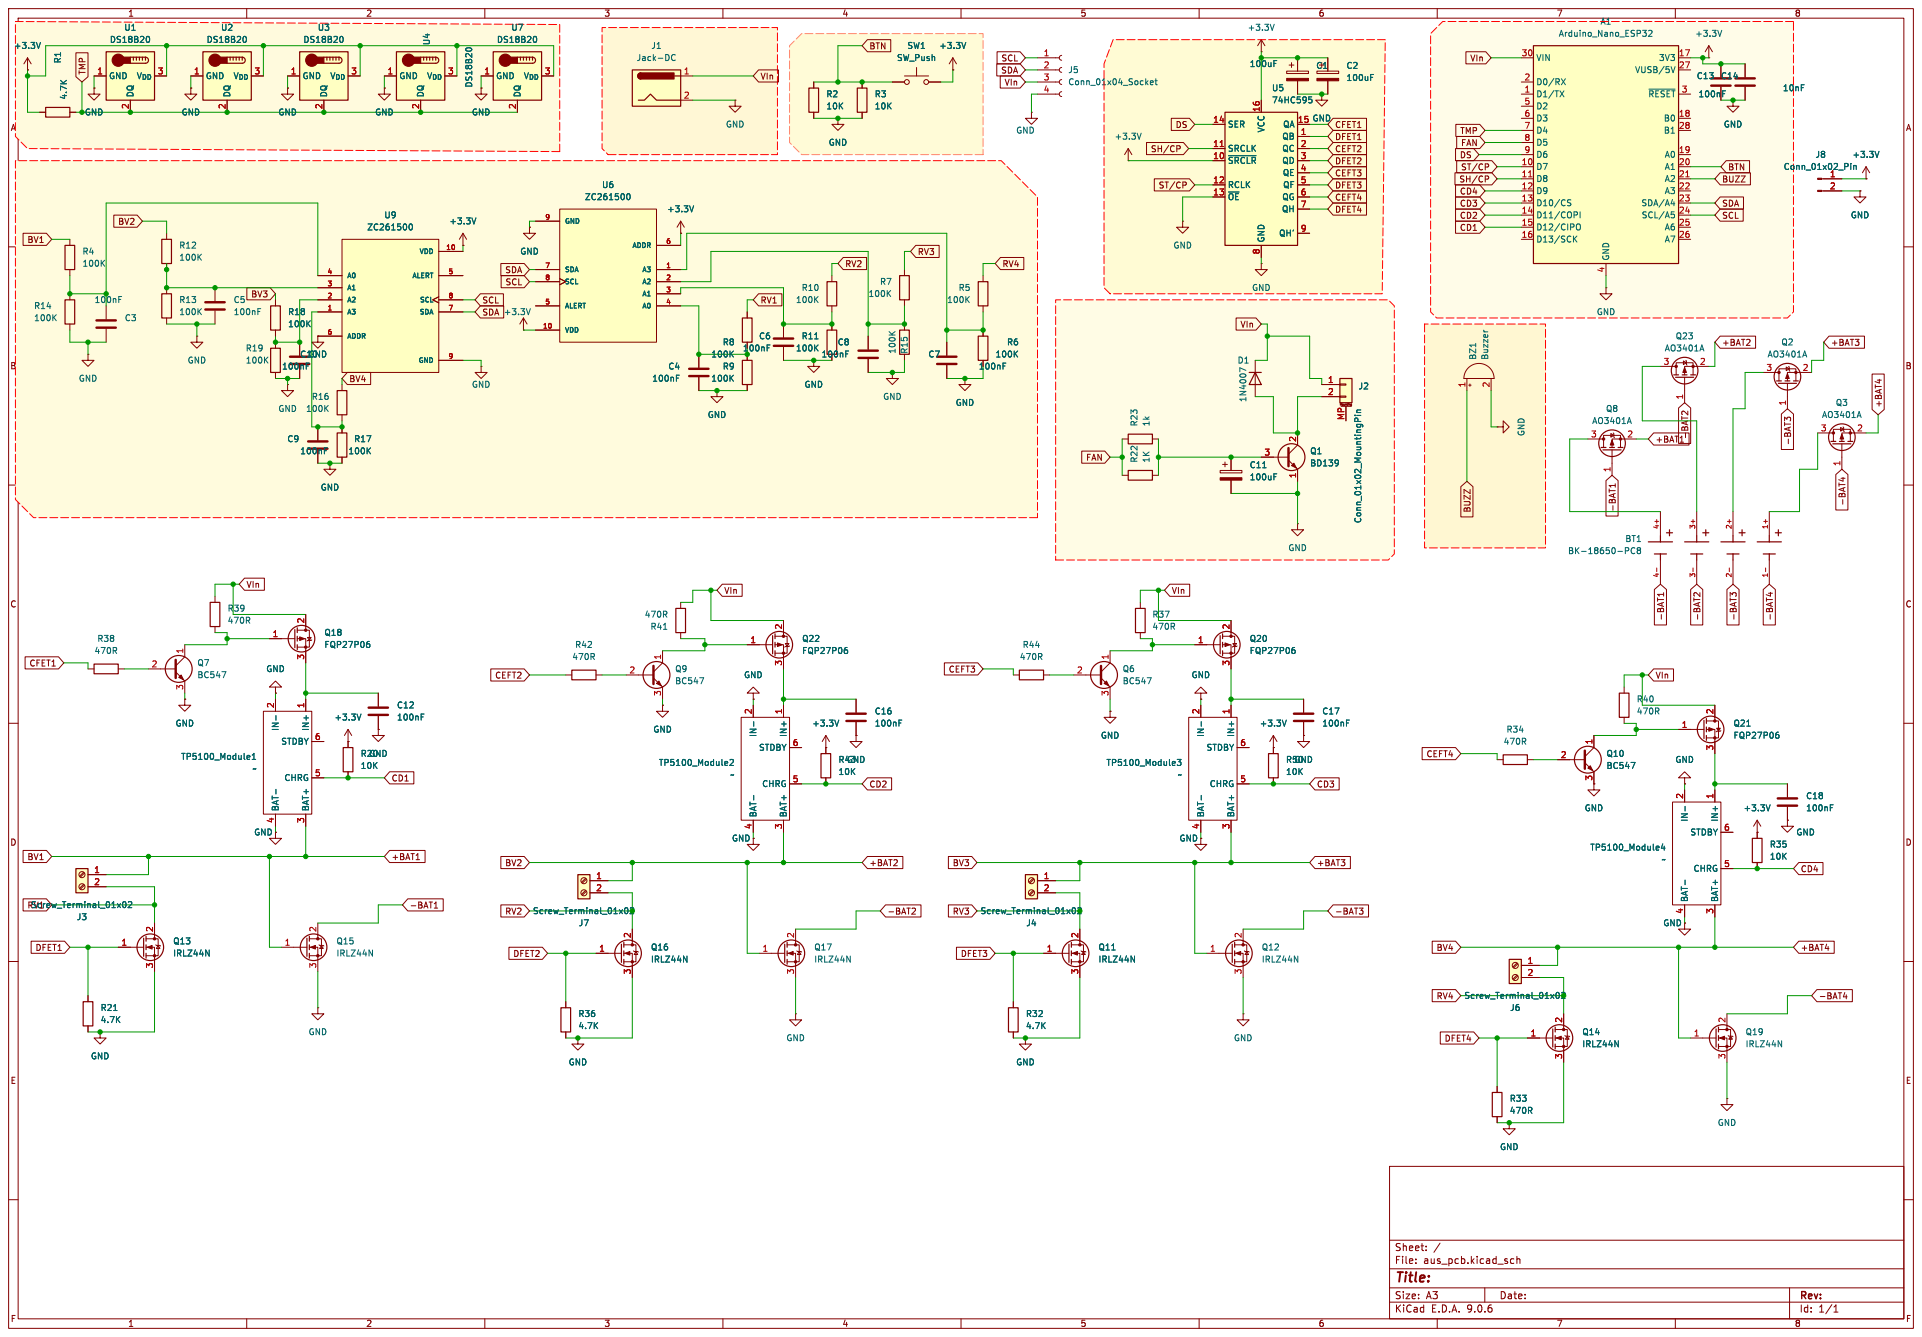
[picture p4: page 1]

2 3 GND GND GND U4 DS18B20 V_{DD} 3 GND 1 DQ

3 STDBY 6 CHRG 5 GND GND GND Q22 FQP27P06

1 3 Q7 BC547 GND GND GND GND

3 STDBY 6 CHRG 5 TP5100_Module2 ~GND GND

Id: 1/1 Title: File: aus_pcb.kicad_sch Sheet: /

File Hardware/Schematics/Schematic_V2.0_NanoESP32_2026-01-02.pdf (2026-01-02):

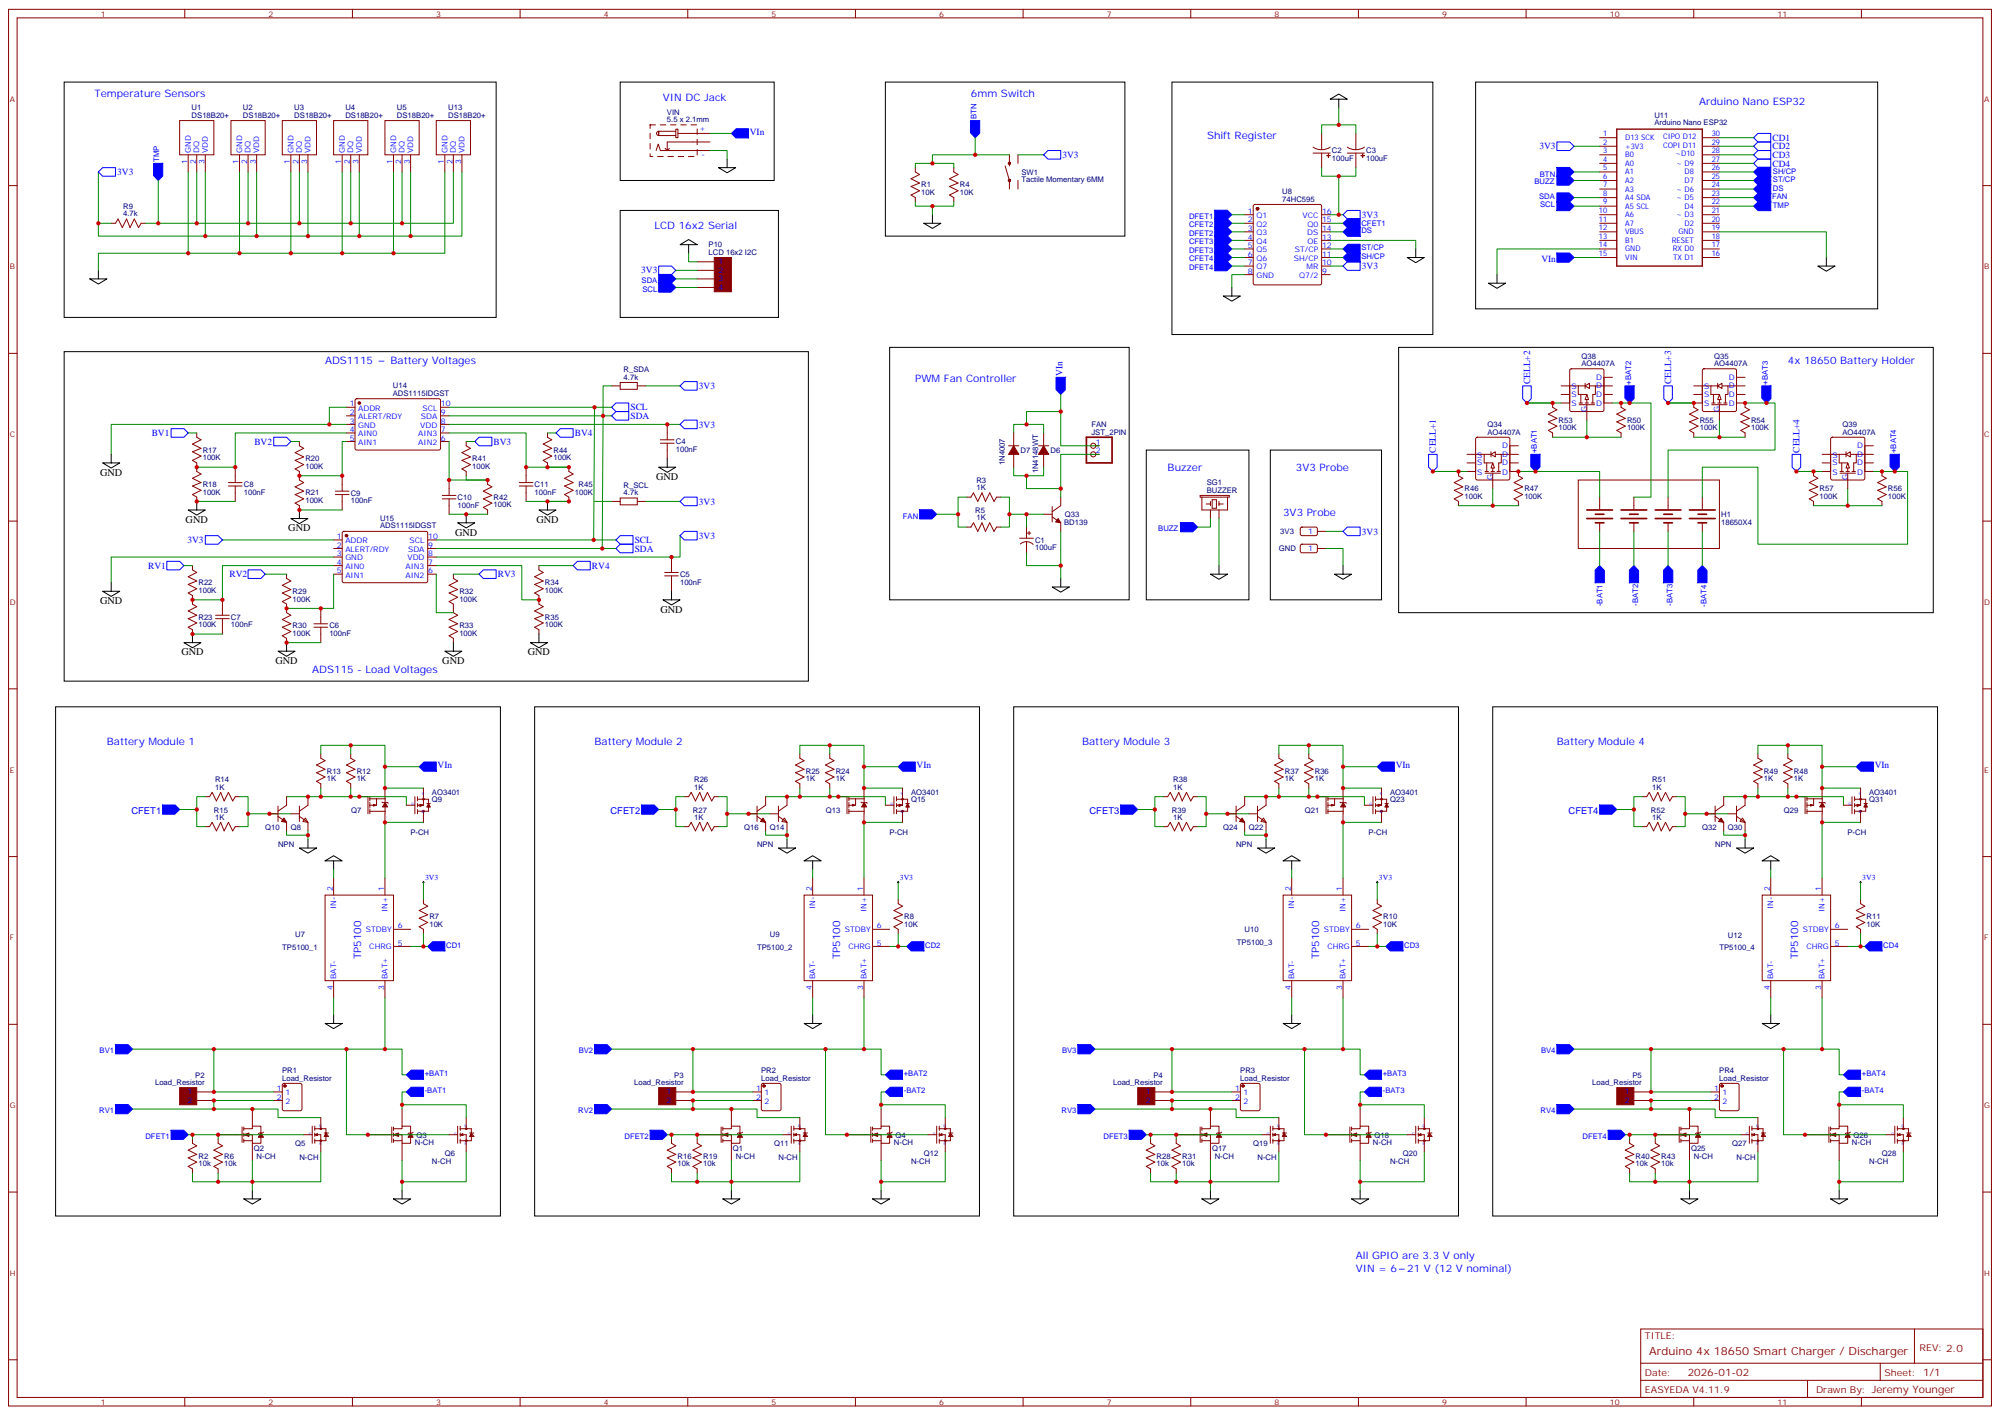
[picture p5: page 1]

All GPIO are 3.3 V only
VIN = 6 21 V (12 V nominal)

TITLE:
Arduino 4x 18650 Smart Charger / Discharger

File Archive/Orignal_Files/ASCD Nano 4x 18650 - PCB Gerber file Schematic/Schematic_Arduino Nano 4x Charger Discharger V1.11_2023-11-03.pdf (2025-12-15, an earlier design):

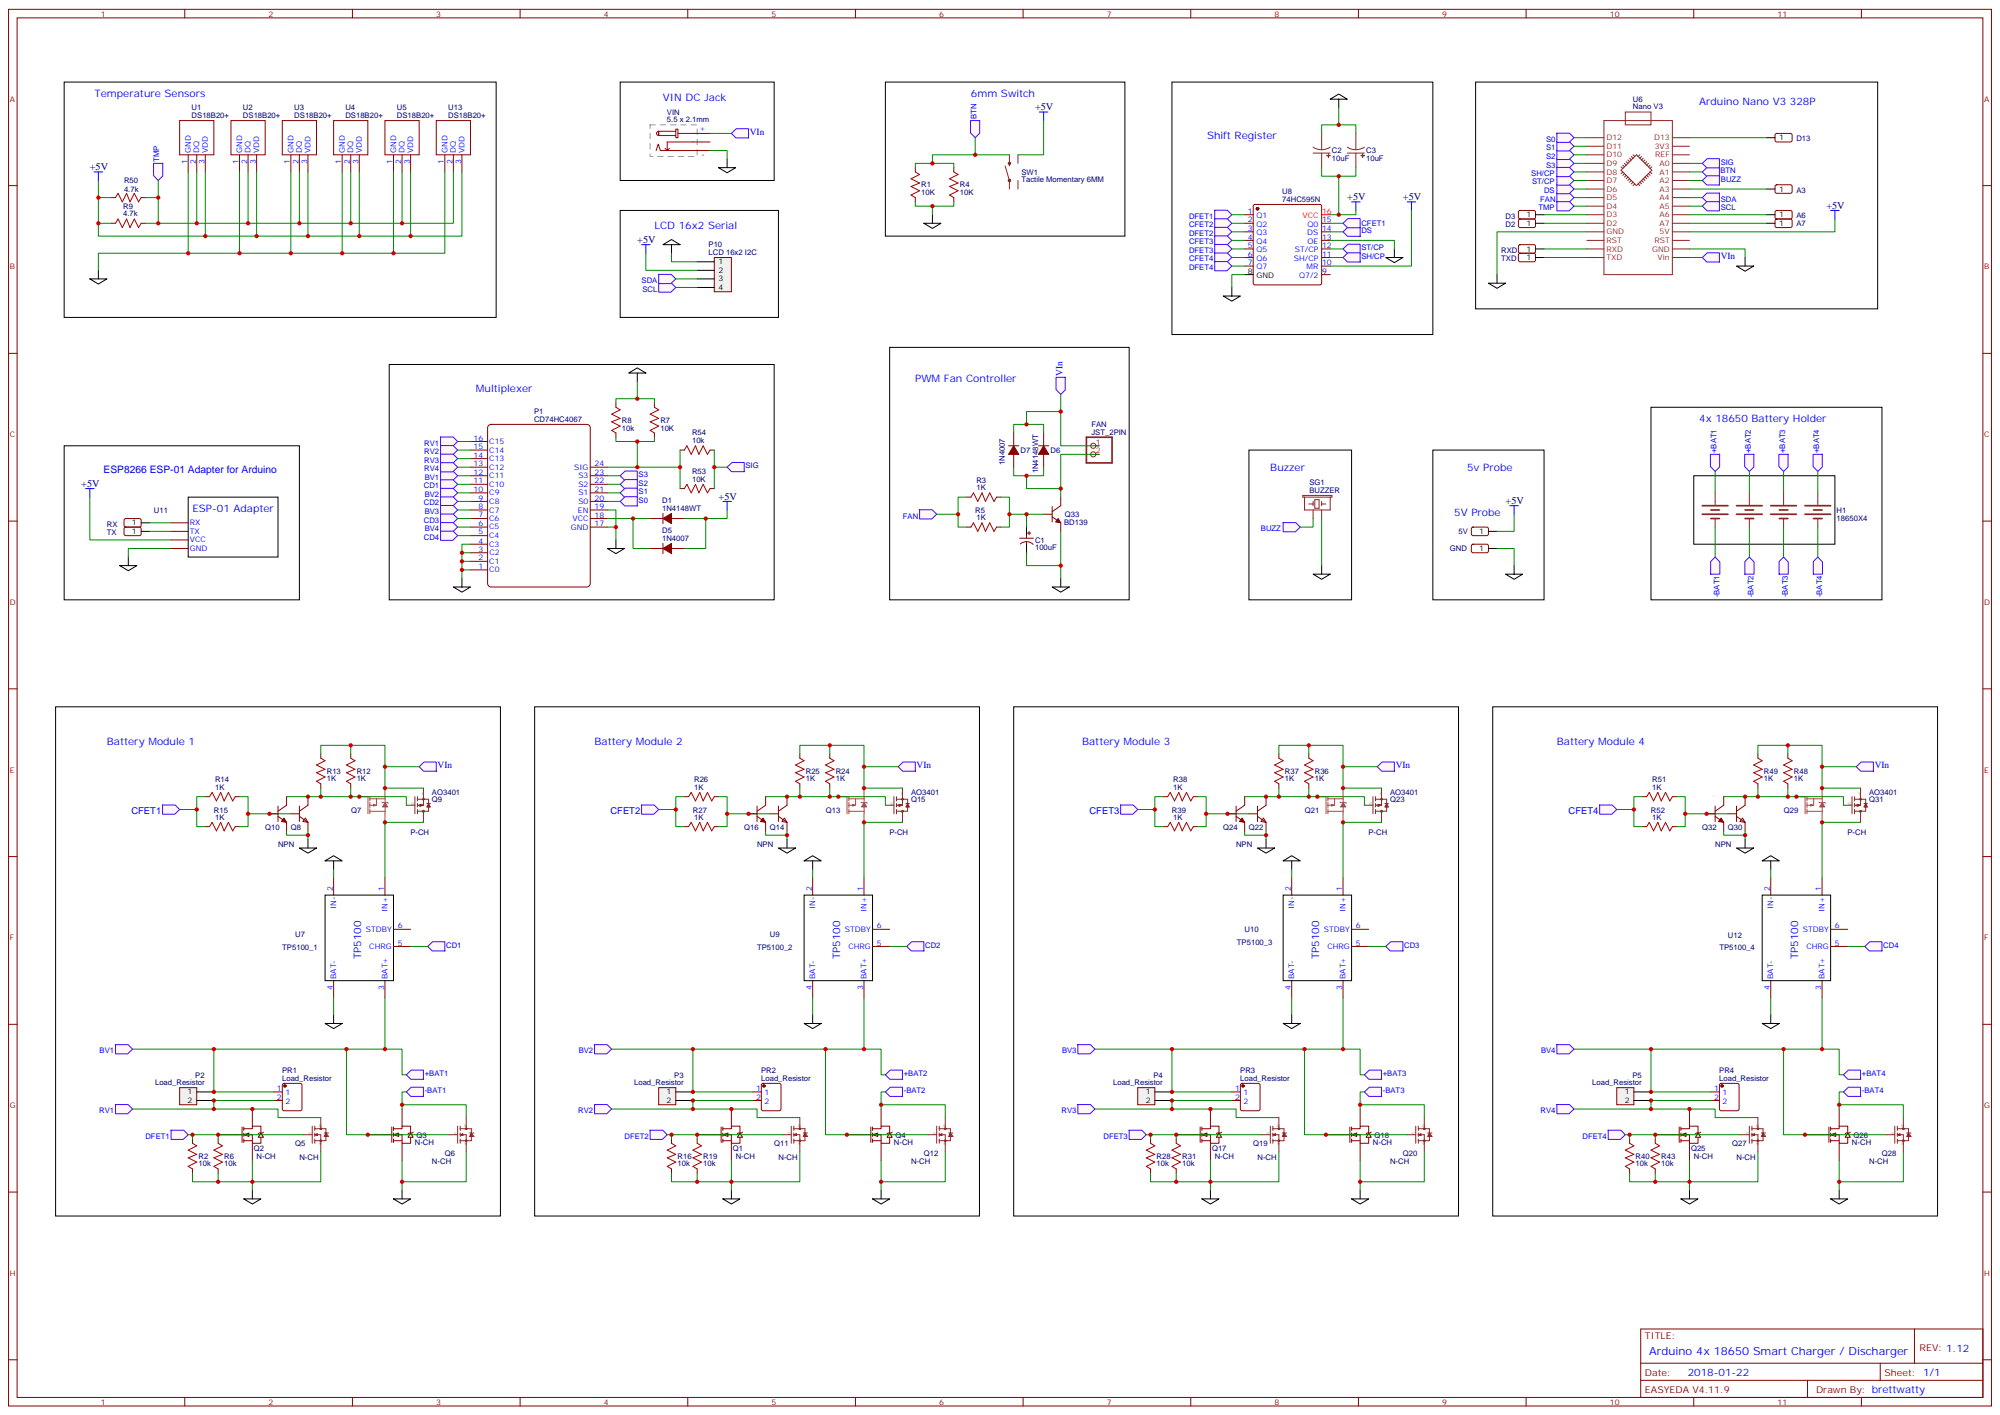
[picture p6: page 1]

ESP8266 ESP-01 Adapter for Arduino

TITLE:
Arduino 4x 18650 Smart Charger / Discharger

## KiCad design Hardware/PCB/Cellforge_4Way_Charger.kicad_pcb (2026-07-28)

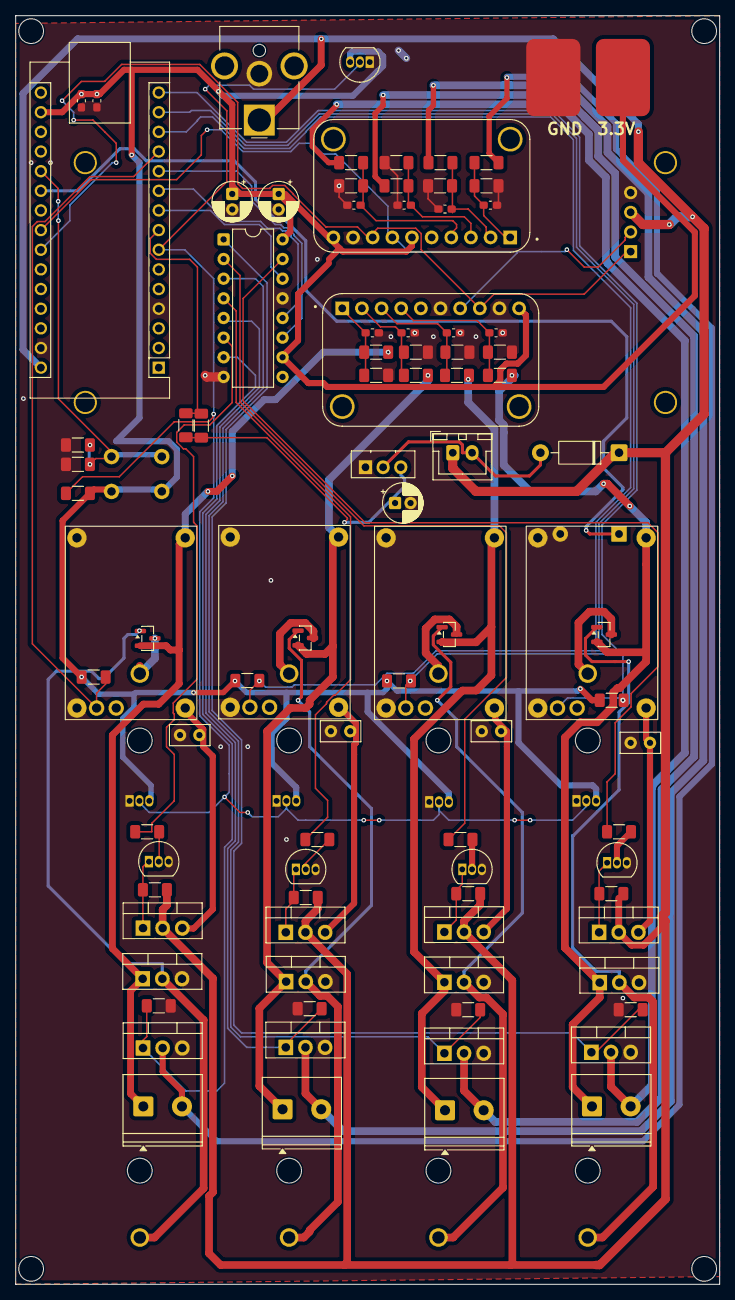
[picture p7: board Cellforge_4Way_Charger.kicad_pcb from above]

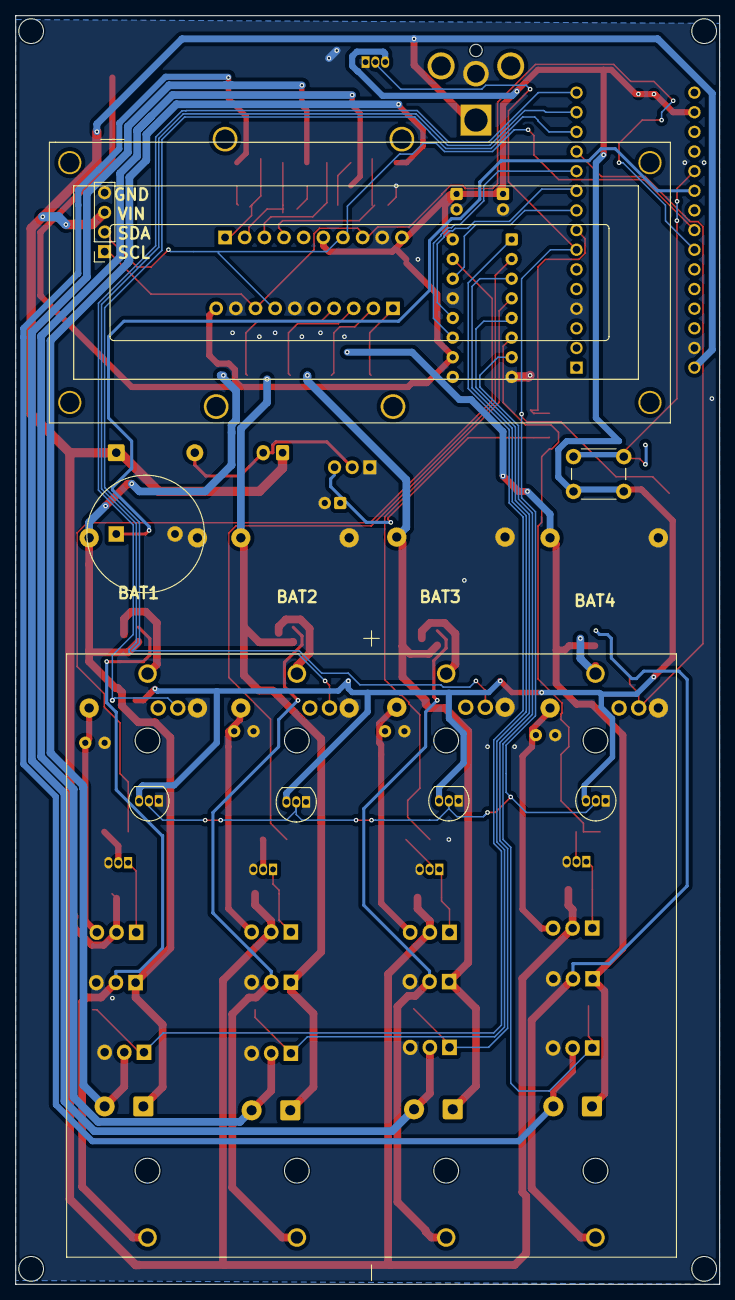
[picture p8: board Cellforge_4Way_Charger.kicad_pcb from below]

Board: 2 copper layers, 91.0 x 164.0 mm, 100 parts (8 on the bottom side), 62 nets.

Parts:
A1: Arduino_Nano_ESP32; Arduino_Nano
BT1: BK-18650-PC8; BAT_BK-18650-PC8
BZ1: Buzzer; Buzzer_15x7.5RM7.6
C1, C2, C11: 100uF; CP_Radial_D5.0mm_P2.00mm
C3, C4, C5, C6, C7, C8, C9, C10, C13: 100nF; C_0603_1608Metric_Pad1.08x0.95mm_HandSolder
C12, C16, C17, C18: C; C_Disc_D5.0mm_W2.5mm_P2.50mm
C14: 10nF; C_0603_1608Metric_Pad1.08x0.95mm_HandSolder
D1: 1N4007; D_DO-41_SOD81_P10.16mm_Horizontal
J1: Jack-DC; BarrelJack_CUI_PJ-063AH_Horizontal_CircularHoles
J2: Conn_01x02_MountingPin; JST_XH_B2B-XH-A_1x02_P2.50mm_Vertical
J3, J4, J6, J7: Screw_Terminal_01x02; TerminalBlock_Phoenix_PT-1,5-2-5.0-H_1x02_P5.00mm_Horizontal
J5: Conn_01x04_Socket; PinSocket_1x04_P2.54mm_Vertical
J8: Conn_01x02_Pin; PADS
Q1: BD139; TO-126-3_Vertical
Q2, Q3, Q8, Q23: AO3401A; SOT-23
Q6, Q7, Q9, Q10: BC547; TO-92_Inline
Q11, Q12, Q13, Q14, Q15, Q16, Q17, Q19: IRLZ44N; TO-220-3_Vertical
Q18, Q20, Q21, Q22: FQP27P06; TO-220-3_Vertical
R1, R21, R32, R36: 4.7K; R_1206_3216Metric_Pad1.30x1.75mm_HandSolder
R2, R3, R20, R35, R43, R50: 10K; R_1206_3216Metric_Pad1.30x1.75mm_HandSolder
R4, R5, R6, R7, R8, R9, R10, R11, R12, R13, R14, R15, R16, R17, R18, R19: 100K; R_1206_3216Metric_Pad1.30x1.75mm_HandSolder
R22: 1K; R_1206_3216Metric_Pad1.30x1.75mm_HandSolder
R23: 1k; R_1206_3216Metric_Pad1.30x1.75mm_HandSolder
R33, R34, R37, R38, R39, R40, R41, R42, R44: 470R; R_1206_3216Metric_Pad1.30x1.75mm_HandSolder
SW1: SW_Push; SW_PUSH_6mm
TP5100_Module1, TP5100_Module2, TP5100_Module3, TP5100_Module4: Untitled
U1, U2, U3, U4, U7: DS18B20; TO-92_Inline
U5: 74HC595; DIP-16_W7.62mm
U6, U9: ZC261500; MODULE_ZC261500

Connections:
+3.3V: A1.17 (3V3), C1.1, C2.1, C13.1, C14.1, J8.1, R1.1, R20.1, R35.1, R43.1, R50.1, SW1.2, U1.3 (V_{DD}), U2.3 (V_{DD}), U3.3 (V_{DD}), U4.3 (V_{DD}), U5.10 (~SRCLR), U5.16 (VCC), U6.6 (ADDR), U6.10 (VDD), U7.3 (V_{DD}), U9.10 (VDD)
+BAT1: J3.1, Q8.2 (S), Q15.1 (G), R4.1, TP5100_Module1.3 (BAT+)
+BAT2: J7.1, Q17.1 (G), Q23.2 (S), R12.1, TP5100_Module2.3 (BAT+)
+BAT3: J4.1, Q2.2 (S), Q12.1 (G), R18.1, TP5100_Module3.3 (BAT+)
+BAT4: J6.1, Q3.2 (S), Q19.1 (G), R16.1, TP5100_Module4.3 (BAT+)
-BAT1: BT1.4-, Q8.1 (G), Q15.2 (D)
-BAT2: BT1.3-, Q17.2 (D), Q23.1 (G)
-BAT3: BT1.2-, Q2.1 (G), Q12.2 (D)
-BAT4: BT1.1-, Q3.1 (G), Q19.2 (D)
BTN: A1.20 (A1), R2.2, R3.1, SW1.1
BUZZ: A1.21 (A2), BZ1.1 (+)
CD1: A1.15 (D12/CIPO), R20.2, TP5100_Module1.5 (CHRG)
CD2: A1.14 (D11/COPI), R43.2, TP5100_Module2.5 (CHRG)
CD3: A1.13 (D10/CS), R50.2, TP5100_Module3.5 (CHRG)
CD4: A1.12 (D9), R35.2, TP5100_Module4.5 (CHRG)
CEFT2: R42.2, U5.2 (QC)
CEFT3: R44.2, U5.4 (QE)
CEFT4: R34.2, U5.6 (QG)
CFET1: R38.2, U5.15 (QA)
DFET1: Q13.1 (G), R21.1, U5.1 (QB)
DFET2: Q16.1 (G), R36.1, U5.3 (QD)
DFET3: Q11.1 (G), R32.1, U5.5 (QF)
DFET4: Q14.1 (G), R33.1, U5.7 (QH)
DS: A1.9 (D6), U5.14 (SER)
FAN: A1.8 (D5), R22.1, R23.1
GND: A1.4 (GND), A1.29 (GND), BZ1.2 (-), C1.2, C2.2, C3.2, C4.2, C5.2, C6.2, C7.2, C8.2, C9.2, C10.2, C11.2, C12.2, C13.2, C14.2, C16.2, C17.2, C18.2, J1.2, J5.4, J8.2, Q1.1 (E), Q6.3 (E), Q7.3 (E), Q9.3 (E), Q10.3 (E), Q11.3 (S), Q12.3 (S), Q13.3 (S), Q14.3 (S), Q15.3 (S), Q16.3 (S), Q17.3 (S), Q19.3 (S), R2.1, R3.2, R6.2, R9.2, R11.2, R13.2, R14.2, R15.2, R17.2, R19.2, R21.2, R32.2, R33.2, R36.2, TP5100_Module1.2 (IN-), TP5100_Module1.4 (BAT-), TP5100_Module2.2 (IN-), TP5100_Module2.4 (BAT-), TP5100_Module3.2 (IN-), TP5100_Module3.4 (BAT-), TP5100_Module4.2 (IN-), TP5100_Module4.4 (BAT-), U1.1 (GND), U2.1 (GND), U3.1 (GND), U4.1 (GND), U5.8 (GND), U5.13 (~OE), U6.9 (GND), U7.1 (GND), U9.6 (ADDR), U9.9 (GND)
unnamed: D1.2 (A), J2.2, Q1.2 (C)
unnamed: C11.1, Q1.3 (B), R22.2, R23.2
unnamed: BT1.2+, Q2.3 (D)
unnamed: BT1.1+, Q3.3 (D)
unnamed: Q6.2 (B), R44.1
unnamed: Q7.2 (B), R38.1
unnamed: BT1.4+, Q8.3 (D)
unnamed: Q9.2 (B), R42.1
unnamed: Q10.2 (B), R34.1
unnamed: Q10.1 (C), Q21.1 (G), R40.2
unnamed: Q7.1 (C), Q18.1 (G), R39.2
unnamed: C12.1, Q18.3 (S), TP5100_Module1.1 (IN+)
unnamed: Q6.1 (C), Q20.1 (G), R37.2
unnamed: C17.1, Q20.3 (S), TP5100_Module3.1 (IN+)
unnamed: C18.1, Q21.3 (S), TP5100_Module4.1 (IN+)
unnamed: Q9.1 (C), Q22.1 (G), R41.1
unnamed: C16.1, Q22.3 (S), TP5100_Module2.1 (IN+)
unnamed: BT1.3+, Q23.3 (D)
unnamed: C4.1, R8.2, R9.1, U6.4 (A0)
unnamed: C6.1, R10.2, R11.1, U6.3 (A1)
unnamed: C8.1, R7.2, R15.1, U6.2 (A2)
unnamed: C7.1, R5.2, R6.1, U6.1 (A3)
unnamed: C3.1, R4.2, R14.1, U9.4 (A0)
unnamed: C5.1, R12.2, R13.1, U9.3 (A1)
unnamed: C10.1, R18.2, R19.1, U9.2 (A2)
unnamed: C9.1, R16.2, R17.1, U9.1 (A3)
RV1: J3.2, Q13.2 (D), R8.1
RV2: J7.2, Q16.2 (D), R10.1
RV3: J4.2, Q11.2 (D), R7.1
RV4: J6.2, Q14.2 (D), R5.1
SCL: A1.24 (SCL/A5), J5.1, U6.8 (SCL), U9.8 (SCL)
SDA: A1.23 (SDA/A4), J5.2, U6.7 (SDA), U9.7 (SDA)
SH/CP: A1.11 (D8), U5.11 (SRCLK)
ST/CP: A1.10 (D7), U5.12 (RCLK)
TMP: A1.7 (D4), R1.2, U1.2 (DQ), U2.2 (DQ), U3.2 (DQ), U4.2 (DQ), U7.2 (DQ)
VIn: A1.30 (VIN), D1.1 (K), J1.1, J2.1, J5.3, Q18.2 (D), Q20.2 (D), Q21.2 (D), Q22.2 (D), R37.1, R39.1, R40.1, R41.2

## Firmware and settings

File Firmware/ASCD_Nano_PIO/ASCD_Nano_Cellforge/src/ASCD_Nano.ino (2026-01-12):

/*
// ASDC Nano 4x Arduino Charger / Discharger
// ---------------------------------------------------------------------------
// Created by Brett Watt on 19/03/2019
// Copyright 2018 - Under creative commons license 3.0:
//
// Modified by Jeremy Younger @darksplat on 06/12/2025
// https://creativecommons.org/licenses/by-nc-sa/3.0/legalcode
*/

#include <Arduino.h>
#include <Wire.h>
#include <WiFi.h>

#include "Pins.h"              // MUST be first custom header
#include "DebugConfig.h"
#include "Temp_Sensor_Serials.h"
#include "Secrets.h"

#include "StatusLED.h"
#include "WifiManager.h"

#include <OneWire.h>
#include <LiquidCrystal_I2C.h>
#include <DallasTemperature.h>
// #include <SoftwareSerial.h>   // Disabled for Nano ESP32


// ----------------------
// Objects
// ----------------------

LiquidCrystal_I2C lcd(0x27, 16, 2);
OneWire oneWire(PIN_TMP);
DallasTemperature sensors(&oneWire);


// ----------------------
// Settings struct (ESP32 / ADS1115 corrected)
// ----------------------

typedef struct
{
  // Hardware calibration
  const float shuntResistor[4]            = {3.3, 3.3, 3.3, 3.3};

  // Charge LED sense thresholds (volts at sense point)
  const float chargeLedPinMidVolatge[4]   = {1.8, 1.8, 1.85, 1.85};

  /*
    referenceVoltage was used on the original Arduino Nano (AVR, 0–5V ADC).
    On ESP32 + ADS1115 this must NOT be used.
    Retained only to avoid breaking legacy paths.
  */
  const float referenceVoltage            = 0.0;   // DEPRECATED – DO NOT USE

  // Battery behaviour
  const float defaultBatteryCutOffVoltage = 2.8;
  const byte  restTimeMinutes             = 1;
  const int   lowMilliamps                = 1000;
  const int   highMilliOhms               = 500;
  const int   offsetMilliOhms             = 0;

  // Safety / timing
  const byte  chargingTimeout             = 8;
  const byte  tempThreshold               = 7;
  const byte  tempMaxThreshold            = 20;
  const float batteryVolatgeLeak           = 0.50;

  // System
  const byte  moduleCount                 = 4;
  const byte  screenTime                  = 4;
  const int   dischargeReadInterval       = 5000;
  const float storageChargeVoltage        = 0.00;

  // Fan
  const byte  pwmFanMinStart              = 115;

} CustomSettings;

CustomSettings settings;


// ----------------------
// Module struct (UNCHANGED)
// ----------------------

typedef struct
{
  const bool batteryVolatgePin[4];
  const bool batteryVolatgeDropPin[4];
  const bool chargeLedPin[4];
  const byte chargeMosfetPin;
  const byte dischargeMosfetPin;

  unsigned long longMilliSecondsCleared;
  byte seconds;
  byte minutes;
  byte hours;

  byte cycleCount;
  bool batteryBarcode;
  bool insertData;
  byte cycleState;
  byte batteryFaultCode;

  float batteryInitialVoltage;
  float batteryVoltage;

  byte batteryInitialTemp;
  byte batteryHighestTemp;
  byte batteryCurrentTemp;
  byte tempCount;

  float tempMilliOhmsValue;
  float milliOhmsValue;

  int intMilliSecondsCount;
  unsigned long longMilliSecondsPreviousCount;
  unsigned long longMilliSecondsPrevious;
  unsigned long longMilliSecondsPassed;
  float dischargeMilliamps;
  float dischargeVoltage;
  float dischargeAmps;
  int dischargeMinutes;
  bool pendingDischargeRecord;
} Modules;

Modules module[4] =
{
  {{1,1,0,1}, {1,1,1,1}, {0,1,0,1}, 0, 1},
  {{1,0,0,1}, {0,1,1,1}, {0,0,0,1}, 2, 3},
  {{1,1,1,0}, {1,0,1,1}, {0,1,1,0}, 4, 5},
  {{1,0,1,0}, {0,0,1,1}, {0,0,1,0}, 6, 7}
};


// ----------------------
// Global state
// ----------------------

byte ambientTemperature = 0;
bool buttonPressed = false;
bool readSerialResponse = false;
char serialSendString[400];
byte countSerialSend = 0;
bool soundBuzzer = false;


// ----------------------
// Forward declarations
// ----------------------

void buzzer();
void fanController();
void sendSerial();
void readSerial();
void returnCodes(int codeID);
void button();
void cycleStateLCD();
void cycleStateLCDOutput(byte j);
void secondsTimer(byte j);
void clearSecondsTimer(byte j);
void initializeVariables(byte j);
void cycleStateValues();
bool dischargeCycle(byte j);
bool chargeCycle(byte j);
byte milliOhms(byte j);
byte getTemperature(byte j);
byte processTemperature(byte j);
void getAmbientTemperature();
bool batteryCheck(byte j);
void digitalSwitch(byte j, bool value);
float readMux(const bool inputArray[]);   // legacy wrapper


// ----------------------
// setup()
// ----------------------

void setup()
{
  // ----------------------
  // Serial bring-up window (ESP32 USB CDC timing)
  // ----------------------
  DBG_BEGIN(115200);
  Serial.setTimeout(5);

  unsigned long serialWaitStart = millis();
  while (!Serial && millis() - serialWaitStart < 3000)
  {
    delay(10);
  }

  DBG_PRINTLN(F(""));
  DBG_PRINTLN(F("===================================="));
  DBG_PRINTLN(F(" ASCD NANO ESP32 BOOT"));
  DBG_PRINTLN(F("===================================="));

  // ----------------------
  // Status LED + Wi-Fi (10 attempts, boot only)
  // ----------------------
  StatusLED::begin();
  connectToWiFi();

  // ----------------------
  // Hardware setup
  // ----------------------

  // Shift register
  pinMode(PIN_SR_DATA, OUTPUT);
  pinMode(PIN_SR_LATCH, OUTPUT);
  pinMode(PIN_SR_CLOCK, OUTPUT);
  digitalWrite(PIN_SR_LATCH, LOW);

  // TP5100 charge status inputs
  pinMode(PIN_CD1, INPUT);
  pinMode(PIN_CD2, INPUT);
  pinMode(PIN_CD3, INPUT);
  pinMode(PIN_CD4, INPUT);

  // Button
  pinMode(PIN_BTN, INPUT);

  // Buzzer
  pinMode(PIN_BUZZ, OUTPUT);
  digitalWrite(PIN_BUZZ, HIGH);
  delay(50);
  digitalWrite(PIN_BUZZ, LOW);

  // Fan
  pinMode(PIN_FAN, OUTPUT);
  ledcSetup(FAN_PWM_CHANNEL, FAN_PWM_FREQ, FAN_PWM_RES);
  ledcAttachPin(PIN_FAN, FAN_PWM_CHANNEL);
  ledcWrite(FAN_PWM_CHANNEL, 0);

  // LCD startup
  lcd.init();
  lcd.clear();
  lcd.backlight();
  lcd.setCursor(0, 0);
  lcd.print(F("ASCD NANO ESP32"));
  lcd.setCursor(0, 1);
  lcd.print(F("Init TP5100....."));

  // Initial module sequence
  for (byte i = 0; i < settings.moduleCount; i++)
  {
    digitalWrite(PIN_FAN, HIGH);

    digitalSwitch(module[i].chargeMosfetPin, 1);
    delay(500);
    digitalSwitch(module[i].chargeMosfetPin, 0);
    delay(500);

    readMux(module[i].batteryVolatgePin);

    digitalSwitch(module[i].dischargeMosfetPin, 1);
    digitalWrite(PIN_FAN, LOW);
    delay(500);
    digitalSwitch(module[i].dischargeMosfetPin, 0);
    delay(500);
  }

  lcd.setCursor(0, 1);
  lcd.print(F("Starting........"));

  sensors.begin();
  lcd.clear();
}


// ----------------------
// loop()
// ----------------------

void loop()
{
  // Status LED engine (non-blocking)
  StatusLED::update();

  if (readSerialResponse)
  {
    readSerial();
  }

  static long buttonMillis;
  static long cycleStateValuesMillis;
  static long sendSerialMillis;
  static long buzzerMillis;

  long currentMillis = millis();

  if (currentMillis - buttonMillis >= 2)
  {
    button();
    buttonMillis = currentMillis;
  }

  if (currentMillis - buzzerMillis >= 50)
  {
    buzzer();
    buzzerMillis = currentMillis;
  }

  if (currentMillis - cycleStateValuesMillis >= 1000)
  {
    cycleStateValues();
    cycleStateValuesMillis = currentMillis;
  }

  if (currentMillis - sendSerialMillis >= 4000)
  {
    if (!readSerialResponse || countSerialSend > 5)
    {
      sendSerial();
      countSerialSend = 0;
    }
    else
    {
      countSerialSend++;
    }
    sendSerialMillis = currentMillis;
  }
}

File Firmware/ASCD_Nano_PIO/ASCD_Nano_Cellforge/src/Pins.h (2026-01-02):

#pragma once

// =====================================================
// Pins.h
// Central pin definitions for ASCD Nano ESP32
// Hardware: Arduino Nano ESP32
// Schematic: Rev 2.0 (ADS1115, no analog mux)
// =====================================================

// =====================================================
// ESP32 Fan PWM (LEDC)
// =====================================================
#define FAN_PWM_CHANNEL   0
#define FAN_PWM_FREQ      25000   // 25 kHz (quiet fan)
#define FAN_PWM_RES       8        // 8-bit resolution

// ----------------------
// I2C (shared bus)
// ----------------------
static const uint8_t PIN_SDA = A4;
static const uint8_t PIN_SCL = A5;


// ----------------------
// 74HC595 Shift Register
// ----------------------
static const uint8_t PIN_SR_DATA = D6;   // DS
static const uint8_t PIN_SR_LATCH = D7;  // ST/CP
static const uint8_t PIN_SR_CLOCK = D8;  // SH/CP


// ----------------------
// TP5100 Charge Status Inputs
// (one per slot, no mux)
// ----------------------
static const uint8_t PIN_CD1 = D12;
static const uint8_t PIN_CD2 = D11;
static const uint8_t PIN_CD3 = D10;
static const uint8_t PIN_CD4 = D9;


// ----------------------
// Fan + Temperature
// ----------------------
static const uint8_t PIN_FAN = D5;   // PWM fan control
static const uint8_t PIN_TMP = D4;   // OneWire temperature bus


// ----------------------
// Button + Buzzer
// ----------------------
static const uint8_t PIN_BTN  = A1;
static const uint8_t PIN_BUZZ = A2;


// ----------------------
// ADS1115 I2C Addresses
// ----------------------
// Battery voltages ADS1115 (ADDR = GND)
static const uint8_t ADS_BAT_ADDR = 0x48;

// Load voltages ADS1115 (ADDR = 3V3)
static const uint8_t ADS_LOAD_ADDR = 0x49;


// ----------------------
// ADS1115 Channel Mapping
// ----------------------
// Battery voltages
static const uint8_t ADS_BV1 = 0; // AIN0
static const uint8_t ADS_BV2 = 1; // AIN1
static const uint8_t ADS_BV3 = 2; // AIN2
static const uint8_t ADS_BV4 = 3; // AIN3

// Load voltages
static const uint8_t ADS_RV1 = 0; // AIN0
static const uint8_t ADS_RV2 = 1; // AIN1
static const uint8_t ADS_RV3 = 2; // AIN2
static const uint8_t ADS_RV4 = 3; // AIN3

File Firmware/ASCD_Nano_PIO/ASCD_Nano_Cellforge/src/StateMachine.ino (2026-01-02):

/*
// ASDC Nano 4x Arduino Charger / Discharger
// ---------------------------------------------------------------------------
// Created by Brett Watt on 19/03/2019
// Modified by Jeremy Younger @darksplat on 06/12/2025
*/

#include <Arduino.h>
#include "Pins.h"


// =====================================================
// External helpers (defined in IOUtils.ino)
// NOTE: Ensure these are NOT declared "static" in IOUtils.ino
// =====================================================
extern int16_t readADS1115(uint8_t i2cAddr, uint8_t channel);
extern float   adsToVoltage(int16_t raw);


// Small local helper: read current battery voltage for slot j (BVj via ADS1115)
static inline float readBatteryVoltage(byte j)
{
  return adsToVoltage(readADS1115(ADS_BAT_ADDR, j));
}


// =====================================================
// Core state machine
// =====================================================

void cycleStateValues()
{
  strcpy(serialSendString, "");
  getAmbientTemperature();
  sprintf_P(serialSendString + strlen(serialSendString), PSTR("&AT=%d"), ambientTemperature);

  for (byte i = 0; i < settings.moduleCount; i++)
  {
    switch (module[i].cycleState)
    {
      case 0: // Check Battery Voltage
        if (batteryCheck(i))
          module[i].cycleCount++;

        if (module[i].cycleCount == 5)
        {
          initializeVariables(i);
          module[i].batteryCurrentTemp = getTemperature(i);
          module[i].batteryInitialTemp = module[i].batteryCurrentTemp;
          module[i].batteryHighestTemp = module[i].batteryCurrentTemp;

          clearSecondsTimer(i);

          // Battery voltage now comes from ADS1115
          module[i].batteryVoltage        = readBatteryVoltage(i);
          module[i].batteryInitialVoltage = module[i].batteryVoltage;

          module[i].cycleState = 1; // -> barcode
          module[i].cycleCount = 0;
        }

        sprintf_P(serialSendString + strlen(serialSendString), PSTR("&CS%d=0"), i);
        break;

      case 1: // Battery Barcode
        module[i].batteryVoltage = readBatteryVoltage(i);

        if (module[i].batteryBarcode == true)
        {
          clearSecondsTimer(i);
          module[i].batteryInitialVoltage = module[i].batteryVoltage;
          module[i].cycleState = 2; // -> charge
        }

        // Battery removed?
        if (!batteryCheck(i))
          module[i].cycleCount++;

        if (module[i].cycleCount == 5)
        {
          module[i].cycleState = 0;
          module[i].cycleCount = 0;
        }

        sprintf_P(serialSendString + strlen(serialSendString), PSTR("&CS%d=1"), i);
        break;

      case 2: // Charge Battery
        module[i].batteryVoltage = readBatteryVoltage(i);

        sprintf_P(serialSendString + strlen(serialSendString),
                  PSTR("&CS%d=2&TI%d=%d&IT%d=%d&IV%d=%d.%02d&CT%d=%d&CV%d=%d.%02d&HT%d=%d"),
                  i, i,
                  (module[i].seconds + (module[i].minutes * 60) + (module[i].hours * 3600)),
                  i, module[i].batteryInitialTemp,
                  i, (int)module[i].batteryInitialVoltage, (int)(module[i].batteryInitialVoltage * 100) % 100,
                  i, module[i].batteryCurrentTemp,
                  i, (int)module[i].batteryVoltage, (int)(module[i].batteryVoltage * 100) % 100,
                  i, module[i].batteryHighestTemp);

        if (processTemperature(i) == 2)
        {
          digitalSwitch(module[i].chargeMosfetPin, 0);
          module[i].batteryFaultCode = 7;

          if (module[i].insertData == true)
          {
            clearSecondsTimer(i);
            module[i].insertData = false;
            module[i].cycleState = 7;
            module[i].cycleCount = 0;
          }
          sprintf_P(serialSendString + strlen(serialSendString), PSTR("&ID%d"), i);
        }
        else
        {
          digitalSwitch(module[i].chargeMosfetPin, 1);

          module[i].cycleCount = module[i].cycleCount + chargeCycle(i);
          if (module[i].cycleCount >= 10)
          {
            digitalSwitch(module[i].chargeMosfetPin, 0);

            if (module[i].insertData == true)
            {
              module[i].insertData = false;
              module[i].cycleState = 3; // -> resistance
              module[i].cycleCount = 0;
            }
            sprintf_P(serialSendString + strlen(serialSendString), PSTR("&ID%d"), i);
          }
        }

        if (module[i].hours == settings.chargingTimeout)
        {
          digitalSwitch(module[i].chargeMosfetPin, 0);
          module[i].batteryFaultCode = 9;

          if (module[i].insertData == true)
          {
            clearSecondsTimer(i);
            module[i].insertData = false;
            module[i].cycleState = 7;
            module[i].cycleCount = 0;
          }
          sprintf_P(serialSendString + strlen(serialSendString), PSTR("&ID%d"), i);
        }
        break;

      case 3: // Check Battery Milli Ohms
        module[i].cycleCount = module[i].cycleCount + milliOhms(i);
        module[i].tempMilliOhmsValue = module[i].tempMilliOhmsValue + module[i].milliOhmsValue;

        if (module[i].cycleCount == 4)
        {
          module[i].milliOhmsValue = module[i].tempMilliOhmsValue / 4;

          if (module[i].milliOhmsValue > settings.highMilliOhms)
          {
            module[i].batteryFaultCode = 3;
            module[i].cycleState = 7;
            module[i].cycleCount = 0;
          }
          else
          {
            if (module[i].minutes <= 1)
            {
              module[i].cycleState = 5;
              module[i].cycleCount = 0;
            }
            else
            {
              module[i].cycleState = 4;
              module[i].cycleCount = 0;
            }
          }
          clearSecondsTimer(i);
        }

        sprintf_P(serialSendString + strlen(serialSendString),
                  PSTR("&CS%d=3&MO%d=%d&CV%d=%d.%02d"),
                  i, i, (int)module[i].milliOhmsValue,
                  i, (int)module[i].batteryVoltage, (int)(module[i].batteryVoltage * 100) % 100);
        break;

      case 4: // Rest Battery
        module[i].batteryVoltage = readBatteryVoltage(i);
        module[i].batteryCurrentTemp = getTemperature(i);

        if (module[i].minutes == settings.restTimeMinutes)
        {
          module[i].batteryInitialVoltage = module[i].batteryVoltage;
          clearSecondsTimer(i);
          module[i].cycleState = 5;
        }

        sprintf_P(serialSendString + strlen(serialSendString),
                  PSTR("&CS%d=4&TI%d=%d&CT%d=%d&CV%d=%d.%02d"),
                  i, i,
                  (module[i].seconds + (module[i].minutes * 60) + (module[i].hours * 3600)),
                  i, module[i].batteryCurrentTemp,
                  i, (int)module[i].batteryVoltage, (int)(module[i].batteryVoltage * 100) % 100);
        break;
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

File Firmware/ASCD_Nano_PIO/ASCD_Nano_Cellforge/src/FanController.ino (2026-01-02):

/*
// ASDC Nano 4x Arduino Charger / Discharger
// ---------------------------------------------------------------------------
// Created by Brett Watt on 19/03/2019
// Modified by Jeremy Younger @darksplat on 06/12/2025
*/

#include <Arduino.h>
#include "Pins.h"

// =====================================================
// Fan controller (ESP32-safe PWM)
// =====================================================

void fanController()
{
  static bool fanOn = false;
  const byte fanTempMin = 28; // °C
  const byte fanTempMax = 38; // °C
  bool dischargeFanOn = false;

  // Force fan full speed if any module is discharging
  for (byte j = 0; j < settings.moduleCount; j++)
  {
    if (module[j].cycleState == 5) // Discharge state
    {
      dischargeFanOn = true;
      break;
    }
  }

  if (dischargeFanOn)
  {
    ledcWrite(FAN_PWM_CHANNEL, 255);
    fanOn = true;
    return;
  }

  if (ambientTemperature < fanTempMin)
  {
    ledcWrite(FAN_PWM_CHANNEL, 0);
    fanOn = false;
  }
  else if (ambientTemperature < fanTempMax)
  {
    int fanSpeed = map(ambientTemperature,
                       fanTempMin,
                       fanTempMax,
                       settings.pwmFanMinStart,
                       252);

    if (!fanOn)
    {
      // Kick-start fan
      ledcWrite(FAN_PWM_CHANNEL, 255);
      fanOn = true;
    }
    else
    {
      ledcWrite(FAN_PWM_CHANNEL, fanSpeed);
    }
  }
  else
  {
    ledcWrite(FAN_PWM_CHANNEL, 255);
    fanOn = true;
  }
}

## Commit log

2025-12-15 Update README with project details and guidelines
    Expanded project details, safety notices, repository structure, current status, getting started guide, contributing guidelines, license information, and credits.
2025-12-15 import: legacy Arduino Nano 4x charger baseline and reference material
    [Gerber_BoardOutline.GKO, Gerber_BottomLayer.GBL, Gerber_BottomPasteMaskLayer.GBP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]
2026-01-02 Add files via upload
    Schematic v2.0
2026-01-02 Add V2 schematic change summary for smart charger
    This document summarizes the schematic changes made in V2 of the Arduino 4× 18650 Smart Charger, detailing modifications to the microcontroller, measurement architecture, and pin mapping.
2026-01-02 Add ADS1115 Technical Note
    This technical note explains the rationale for selecting the ADS1115, its configuration in the V2 schematic, and how it enhances the design by replacing the analogue multiplexer used in the original 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
2026-01-02 Update changelog for ESP32 Nano hardware refactor
    Finalised migration to Arduino Nano ESP32 with new ADC architecture. Removed analogue multiplexer and standardised I²C bus.
2026-01-02 Update changelog for ESP32 Nano hardware refactor
    Finalised migration to Arduino Nano ESP32 with dual ADS1115 architecture. Updated power strategy and resolved mixed-voltage logic issues.
2026-01-12 Revise CellForge roadmap with implementation details
    Updated the CellForge roadmap to include current implementation status, pending UI work, and planned features, while clarifying out-of-scope items.
2026-01-12 Revise CellForge roadmap with current and planned features
    Updated the roadmap to reflect the current implementation status and planned development for the CellForge project, including sections on hardware, firmware, website development, and documentation.
2026-07-28 Hardware files
    [Cellforge_4Way_Charger.kicad_pcb, Cellforge_4Way_Charger.kicad_pcb_bom.csv, Cellforge_4Way_Charger.kicad_pcb_positions.csv]
